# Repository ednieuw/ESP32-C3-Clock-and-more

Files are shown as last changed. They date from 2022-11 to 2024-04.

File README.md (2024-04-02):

<h1 class="auto-style10">ESP32-C3-12F ESP32-S3 Word clock, HTML page, NTP, BLE to phone and more</h1>

Ed's GitHub stats (https://github.com/anuraghazra/github-readme-stats)

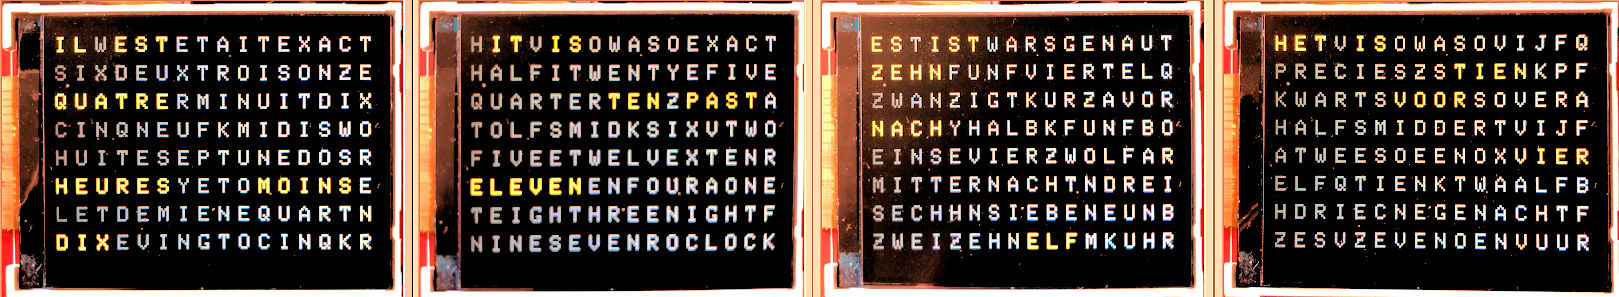
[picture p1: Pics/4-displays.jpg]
4-displays

<p><span class="auto-style10">A small clock that displays the time in words in Dutch, English, French and 
German.<br />The clock is able to receive time via NTP from the internet. <br />
Settings can be controlled via a webpage, PC and Bluetooth LE.</span><br />
Also info here: <a href="https://ednieuw.home.xs4all.nl/Woordklok/ESP32C3AndMore/ESP32C3ClockAndMoreV.html">  
On my home page for the latest info</a>.	
<p><span class="auto-style10">The clock is built with an ESP32-C3-12F kit.</span><br class="auto-style10" />
<span class="auto-style10">The software is written with the Arduino IDE 1.8.19.</span><br class="auto-style10" />
<br class="auto-style10" />
<span class="auto-style10">The software contains coding to use:</span><br class="auto-style10" />
1 ILI9314 colour display</br>
2 BLE nRF UART connection with a phone with an option to send strings longer than 20 bytes</br>
3 Time zone corrected time with daylight savings from a NTP server via WIFI</br>
4 RGBCW LED control on the MCU board</br>
5 RTC for time keeping when off line</br>
6 LDR analogue readings&nbsp;and control of display intensity</br>
7 Storage of the settings in the ESP32-C3 SPIFSS Flash memor</br>
8 Menu driven control of preferences with serial monitor, BLE and WIFI-html page</br>
9&nbsp;Four languages to display time</br>
10 SK6812 RGBW /WS2812 RGB LED strip support to make a word clock</br>
11 Analog clock.</br>
12 OTA. Upgrade the software over the air without USB-cable</br> </span></p>
<p style="width: 840px"><br class="auto-style10" />
<table class="auto-style12">
<tr>
<td style="width: 377px" valign="bottom"><span class="auto-style3"><br />
</span><span class="auto-style11">Het was tien over tien&nbsp;&nbsp;&nbsp;&nbsp; 10:13:00</span><br class="auto-style11" />
<span class="auto-style11">Il est dix heures et quart 10:14:00</span><br class="auto-style11" />
<span class="auto-style11">Il est dix heures et quart 10:15:00</span><br class="auto-style11" />
<span class="auto-style11">Het is kwart over tien&nbsp;&nbsp;&nbsp;&nbsp; 10:16:00</span><br class="auto-style11" />
<span class="auto-style11">Es war viertel nach zehn&nbsp;&nbsp; 10:17:00</span><br class="auto-style11" />
<span class="auto-style11">It was quarter past ten&nbsp;&nbsp;&nbsp; 10:18:00</span><br class="auto-style11" />
<span class="auto-style11">Il est dix heures vingt&nbsp;&nbsp;&nbsp; 10:19:00</span><br class="auto-style11" />
<span class="auto-style11">Es ist zehn vor halb elf&nbsp;&nbsp; 10:20:00</span><br class="auto-style11" />
<span class="auto-style11">Het is tien voor half elf&nbsp; 10:21:00</span><br class="auto-style11" />
<span class="auto-style11">It was twenty past ten&nbsp;&nbsp;&nbsp;&nbsp; 10:22:00</span><br class="auto-style11" />
<span class="auto-style11">It was twenty past ten&nbsp;&nbsp;&nbsp;&nbsp; 10:23:00</span><br class="auto-style11" />
<span class="auto-style11">Het is vijf voor half elf&nbsp; 10:24:00</span><br class="auto-style11" />
<span class="auto-style11">Es ist funf vor halb elf&nbsp;&nbsp; 10:25:00</span><br class="auto-style11" />
<span class="auto-style11">It is twenty five past ten 10:26:00</span><br class="auto-style11" />
<span class="auto-style11">Es war funf vor halb elf&nbsp;&nbsp; 10:27:00</span><span class="auto-style3"><br />
<br />
</span></td>
<td>
<span class="auto-style3">
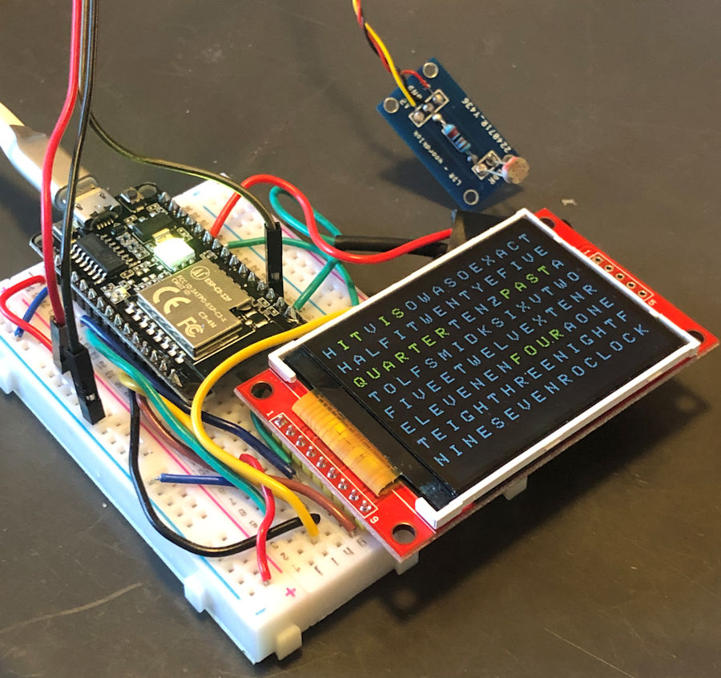
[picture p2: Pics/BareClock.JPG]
Bare clock
</span></td>
</tr>
<tr>
<td class="auto-style10" colspan="2">Display of the time in the serial output</td>
</tr>
</table>
<br class="auto-style10" />
</p>
<h2 style="width: 840px"><strong>Introduction</strong></h2>
<p style="width: 840px" class="auto-style10">The ESP32-C3-12F is a cheap, versatile Micro Computer Unit (MCU). <br />
Competitors at this moment, end 2022, I have played with are the Arduino MKR1010 
and IOT33, the Arduino RP2040 Connect and Raspberry Pico W.<br />
The RP2040 Connect is my favorite at the moment while it pins are compatible with the Arduino 
Nano / Every and my designed printed circuit boards (PCB) can still be used, it has a lot a memory and more than enough speed 
for my projects<br />
A <a href="https://ednieuw.home.xs4all.nl/Woordklok/Pocuter/PocuterWordClockV.html">kickstarter project</a> using the 
ESP32-C3 with an OLED display forced me to study this architecture. <br />
A piece of cake was my first thought and I started to convert the word clock 
into the ESP-C3.<br />
Source code for an Arduino also compiles and uploads with the Arduino IDE 
in a ESP32-C3.<br />
But many libraries are different and changing from 5V and 3.3V was needed.&nbsp;
<br />
The result is the program and design below.&nbsp; <br />
Everything works and the time is displayed in words in the display.<br />
The program's origin was a <a href="https://ednieuw.home.xs4all.nl/Woordklok/Bouwpakket/WoordklokWitteLEDs.html">word 
clock running with an ATMEGA328 </a>processor. The software was then converted 
to be used with <a href="https://ednieuw.home.xs4all.nl/Woordklok/Bouwpakket/WoordklokSK6812.htm">SK6812 RGBW</a> or<a href="https://ednieuw.home.xs4all.nl/Woordklok/Bouwpakket/Woordklok-Kleur.htm">WS2812 
RGB</a> LED-strips. Time was received with a DCF77 receiver.<br />
<br />
This ESP32-C3 program is able to connect to a NTP service on the internet and is 
attached to an ILI9314 display to print the time as text. The ILI9341 colour display is, around €10, very cheap 
but not very fast. For this clock it is not an issue. When no connection is made 
the clock runs on the internal RTC but will drift.<br />
Settings can be changed via Bluetooth on a phone or with a webpage in a browser. <br />
No cloud service is used or needed to operate this clock.&nbsp;</p>
<h2 style="width: 840px"><strong>Hardware</strong></h2>
<p style="width: 840px" class="auto-style10"><strong>Materials<br />
- </strong>ESP32-C3-12F<br />
- ILI9341 display<br />
- LDR (Light Dependent Resistor) type GL5516 or GL5528<br />
- Resistors 1 kOhm, 10 kOhm and optional 22 kOhm<br />
- 2N2222 or 2N3906 PNP transistor <strong><br />
<br />
</strong>
<span class="auto-style10">- For IOS:&nbsp;
<a href="https://apps.apple.com/nl/app/ble-serial-pro/id1632245655?l=en">BLE 
Serial Pro</a>. (Turn on Fast BLE with option Z in the menu)</span><br />
<span class="auto-style10">- For Android :
<a href="https://play.google.com/store/apps/details?id=de.kai_morich.serial_bluetooth_terminal">
Serial Bluetooth terminal</a>. (Turn off (default) Fast BLE)</span></p>
<p style="width: 840px" class="auto-style10">The program 
'ESP32C3-WordClockV009.ino' or newer can be uploaded in the 
ESP32-C3-12F with the Arduino IDE 1.8.19 or newer. The Arduino IDE 2.0.2 
(November 2022) was not able to compile this program due to a bug in the IDE.<br /> 
The libraries needed to compile can be installed with the Arduino IDE (Tools -> Manage libraries) or be copied from the V009LibsAndBuilt.zip in the folder 'libraries' located in the sketch book location folder of the IDE. <br />
<br />
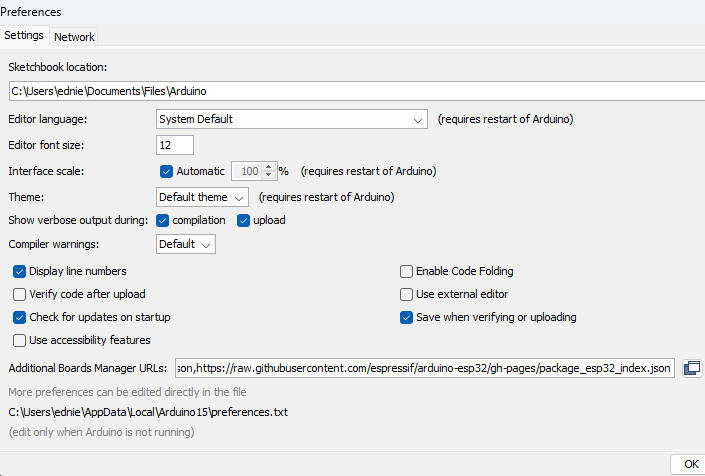
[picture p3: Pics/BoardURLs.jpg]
Boardmanager
</p>
<p style="width: 840px" class="auto-style10"><br />
Add the string in Additional Boards Manager URLs in File-&gt; Preference of the IDE<strong><br />
</strong><span class="auto-style11"><span class="auto-style13">
https://raw.githubusercontent.com/espressif/arduino-esp32/gh-pages/package_esp32_index.json
</span><br />
<br />
</span>Restart the IDE and install the ESP32 boards.<br />
<br />
Choose the 'ESP32C3 Dev Module' as board and set the partition scheme to 'huge'
<br />
in the IDE menu --&gt; Tools.</p>
<p style="width: 840px" class="auto-style10"><strong> <br />
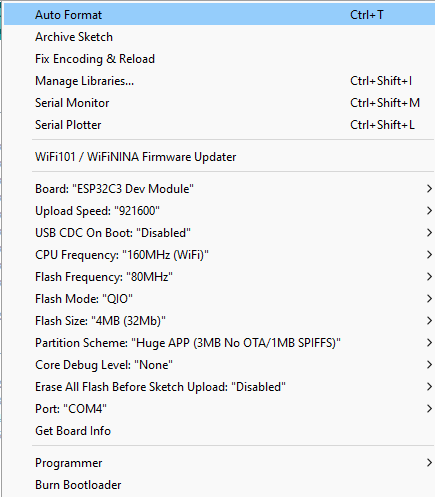
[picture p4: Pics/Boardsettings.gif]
IDE settings
<br />
<br />
</strong>If the program compiles without errors and uploads into the ESP-C3 the 
hardware can be connected to the board.<br />
&nbsp;<strong><br />
</strong>Connect the DC/RS, RST, MOSI, SCK to respectively GPIO pins 06, 07, 08 and 09.<br />
MISO is not used because no data comes back from the display. <br />
CS is connected to GND. <br />
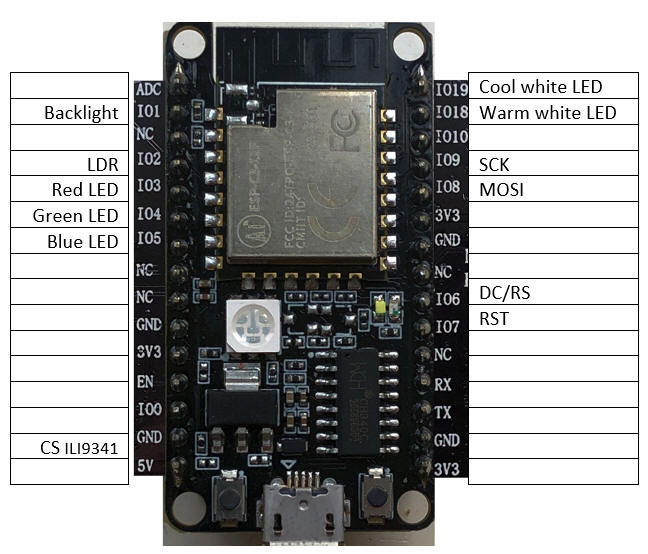
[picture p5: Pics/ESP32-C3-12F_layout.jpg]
ESP32-C3-12F connections
<br />
<br />
To control the brightness of a connected LED-strip or the back light of the 
display a LDR measures the 
luminosity and dims the LEDs or back light accordingly by PWM on the pin that 
powers the back light or changes the RGBW LED intensity in the software. <br />
<br />
If no LDR is attached 
set the minimum light intensity to 254 in the menu and the maximum to 255.<br />
<br />
The back light of the ILI9341 uses 50 - 100 mA and the pins of the ESP32-C3-12F 
supply 12mA (or 40mA?). Therefore a 2N2222 PNP transistor is used. A BC327 did 
not work. Probably 3V3 is too less to switch the transistor. A 2N3906 may also 
work.<br />
<br />
Connect the 1 kOhm resistor to pin GPIO 01 that controls the intensity of the 
backlight.<br />
<br />
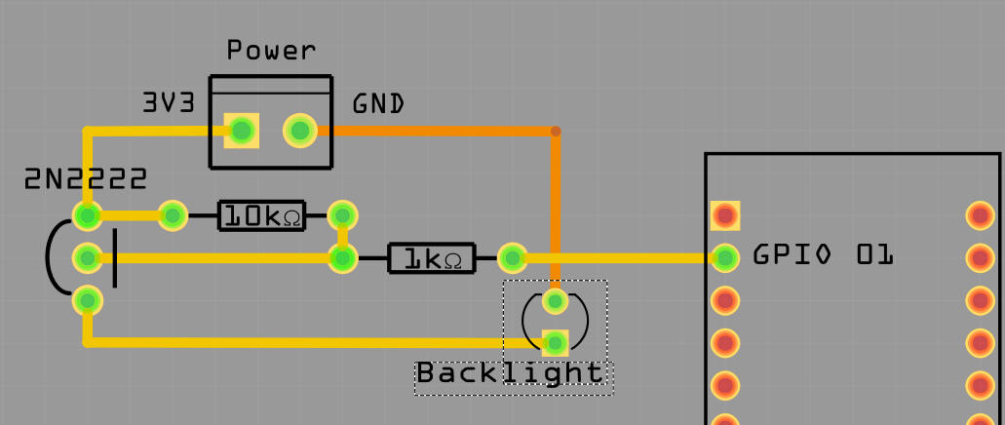
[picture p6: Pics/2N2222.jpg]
PWM 2N2222
<br />
</p>
<p style="width: 840px" class="auto-style10">The LDR is connected via a 10 - 22 
kOhm LDR to ground. The pin A2 is connected to GPIO 02.</p>
<p style="width: 840px" class="auto-style10">With option K in the menu display 
of the LDR readings are printed every second. With the options minimum, maximum 
and slope in the menu the light intensity of the display can be controlled<br />
<br />
<a href="https://ednieuw.home.xs4all.nl/Woordklok/LDR/GL55xxLDRs.html">More about the LDR and it types</a><br />
</p>
<p style="width: 840px" class="auto-style10">
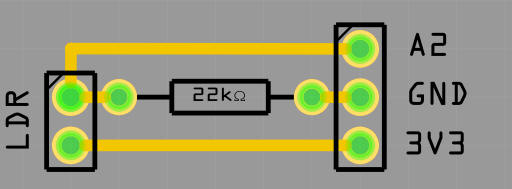
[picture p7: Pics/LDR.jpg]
LDR schakeling
</p>
<p style="width: 840px" class="auto-style10">Connecting the LDR to GPIO 00 
failed. The pin did not go low to 0V. It is used for WIFI?<br />
Almost all&nbsp; the pins are used now. <br />
GPIO 03, 04, 05, 18 and 19 are used for the LEDs on 
the MCU. GPIO 20 and 21 are probably used for the serial USB connection.
&nbsp; <br />

 

</p>
<h2 style="width: 840px"><strong><span class="auto-style10">First Use</span></strong></h2>
<p style="width: 840px"><span class="auto-style10">When the MCU is started and running properly the LED on the 
board will pulse red every second. 
</span> 
<br class="auto-style10" />
<span class="auto-style10">When connected to WIFI&nbsp; the same led will also pulse green.&nbsp; 
</span> <br class="auto-style10" />
<span class="auto-style10">Press the
the top right button to see the IP-address, time and date of the clock.
</span>
<br class="auto-style10" />
<span class="auto-style10">Date and IP-address will disappear as a new minute starts.</span><br class="auto-style10" />
<span class="auto-style10">Enter the IP-address in a browser or connect 
via Bluetooth and send the character 'I' to see for the menu.</span><br class="auto-style10" />
<span class="auto-style10">In the menu the name of the router to connect to, the SSID, and its password can 
be entered. </span> <br class="auto-style10" />
<br class="auto-style10" />
IP-address<br class="auto-style10" />
</p>
<h2><span class="auto-style10"><strong>Control of the clock</strong>&nbsp;
</span></h2>
<p><span class="auto-style10">If the clock is connected to the internet it will seek contact with a time 
server. (NTP connection can be turned off in the menu). </span> <br class="auto-style10" />
<span class="auto-style10">The time zone is set to UTC+1 Amsterdam but can be changed in the menu.</span><br class="auto-style10" />
<span class="auto-style10">To connect to a WIFI network a SSID and password must be entered.</span><br class="auto-style10" />
<span class="auto-style10"><br />
There are a few methods:</span><br class="auto-style10" />
<span class="auto-style10">1. Connect the MCU with a serial cable to a PC and use a serial terminal. I 
use the Arduino IDE or <a href="https://www.compuphase.com/software_termite.htm">
Termite</a> as serial terminal.</span><br class="auto-style10" />
<br class="auto-style10" />
<span class="auto-style10">Sending the character 'I' for information will display the menu followed with the actual 
settings of several preferences.</span></p>
<p>
<table style="width: 51%" class="auto-style12">
<tr>
<td style="width: 342px">
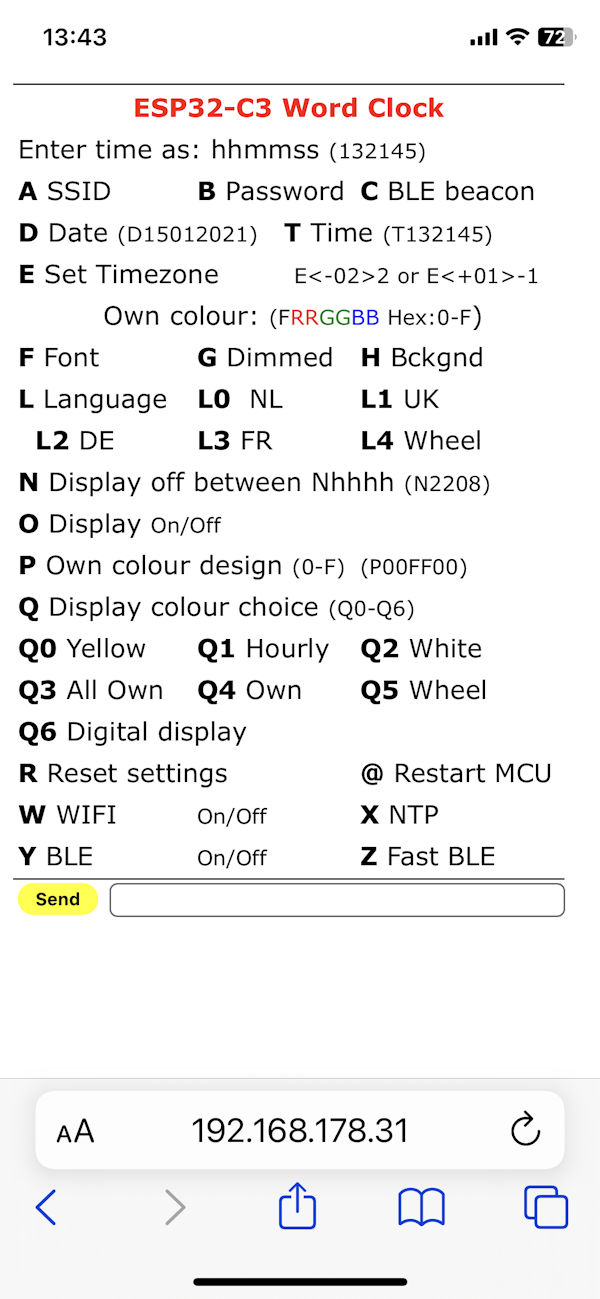
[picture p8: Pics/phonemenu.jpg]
Menu on iPhone
</td>
<td style="width: 415px">
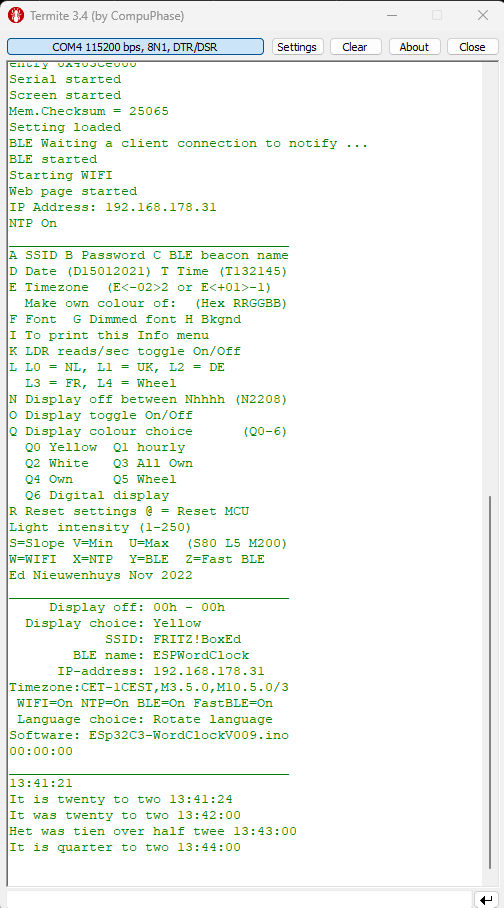
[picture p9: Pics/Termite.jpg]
Termite terminal
</td>
</tr>
<tr>
<td style="width: 342px" class="auto-style10">HTML page on iPhone.</td>
<td style="width: 415px"><br class="auto-style10" />
<span class="auto-style10">Termite Terminal on a PC</span></td>
</tr>
</table>
<br class="auto-style10" />
</p>
<table style="width: 919px">
<tr>
<td style="width: 550px">
<p><span class="auto-style10">2. USE the BLE nRF connection with an UART serial terminal app 
to control it with your mobile phone or tablet.</span><br class="auto-style10" />
<span class="auto-style10"><br />
Use the IOS app for iPhone or iPad:&nbsp;
<a href="https://apps.apple.com/nl/app/ble-serial-pro/id1632245655?l=en">BLE 
Serial Pro</a>. <br />
Turn on Fast BLE with option Z in the menu.</span><br class="auto-style10" />
<br class="auto-style10" />
<span class="auto-style10">For Android use:
<a href="https://play.google.com/store/apps/details?id=de.kai_morich.serial_bluetooth_terminal">
Serial Bluetooth terminal</a>. <br />
Turn off (default) Fast BLE in the menu.</span>
</p>
<p>
<span class="auto-style10">Start the 
app and find the MCU in the list of devices and connect to it. You 
can change it's beacon name in the menu with option C.</span><br class="auto-style10" />
<br class="auto-style10" />
<span class="auto-style10">In both cases 
<strong>send the character I 
of Information and the menu shows up</strong></span>.<br class="auto-style10" />
<span class="auto-style10">Enter the first character of the setting you want to change followed with a code.</span><br class="auto-style10" />
<span class="auto-style10">Some entries just toggle On and Off. Like the W to set WIFI Off or On. 
</span> 
</p>
<p style="width: 600px"><span class="auto-style10">To change the SSID and password:</span><br class="auto-style10" />
<span class="auto-style10"><strong>A</strong></span><span class="auto-style7"><strong>my-ssid</strong></span><span class="auto-style10"> 
and send this command. Eg AFRITZ!Box01 or aFRITZ!Box01. Starting with an upper 
or lower case character is an identical instruction in the command string</span><br class="auto-style10" />
<span class="auto-style10">Then&nbsp; <strong>B</strong></span><span class="auto-style1"><span class="auto-style10"><strong>my-password</strong> and send that password.</span><br class="auto-style10" />
<span class="auto-style10">
<strong>Cbroadcastname</strong>&nbsp;will change to name displayed in the Bluetooth 
connection list.&nbsp; </span> <br class="auto-style10" />
<span class="auto-style10">If the length of the SSID and/or password is less then 5 characters the WIFI 
will be turned off automatically. This will speed up startup time if no internet connection is available</span><br class="auto-style10" />
<span class="auto-style10">Use a length of minimal 8 characters for SSID and password.</span><br class="auto-style10" />
<span class="auto-style10">Check in the menu (third row from the bottom) if WIFI and NTP are on.</span><br class="auto-style10" />
<span class="auto-style10">If WIFI is connected the LED on the MCU will pulse green.</span><br class="auto-style10" />
</span><br class="auto-style10" /><span class="auto-style10">Enter @ to reset the 
MCU. It will restart and connections will be made.</span><br class="auto-style10" />
<br class="auto-style10" />
<span class="auto-style10">To set a time zone. Send the time zone string between the quotes prefixed with 
the character E or e.</span><br class="auto-style10" />
<span class="auto-style10">See the time zones at the bottom of this page.</span><br class="auto-style10" />
<span class="auto-style10">For example; if you live in Australia/Sydney send the string: eAEST-10AEDT,M10.1.0,M4.1.0/3</span></p>
</td>
<td valign="bottom">
<p class="auto-style10">&nbsp;</p>
<pre>___________________________________
A SSID B Password C BLE beacon name
D Date (D15012021) T Time (T132145)
E Timezone (E&lt;-02&gt;2 or E&lt;+01&gt;-1)
Make own colour of: (Hex RRGGBB)
F Font G Dimmed font H Bkgnd
I To print this Info menu
K LDR reads/sec toggle On/Off
L L0 = NL, L1 = UK, L2 = DE
L3 = FR, L4 = Wheel
N Display off between Nhhhh (N2208)
O Display toggle On/Off
Q Display colour choice (Q0-6)
Q0 Yellow Q1 hourly
Q2 White Q3 All Own
Q4 Own Q5 Wheel
Q6 Digital display
R Reset settings @ = Reset MCU
Light intensity (1-250)
S=Slope V=Min U=Max (S80 L5 M200)
W=WIFI X=NTP Y=BLE Z=Fast BLE
Ed Nieuwenhuys Nov 2022
___________________________________
Display off: 00h - 00h
Display choice: Yellow
SSID: FRITZ!BoxEd
BLE name: ESPWordClock
IP-address: 192.168.178.31
Timezone:CET-1CEST,M3.5.0,M10.5.0/3
WIFI=On NTP=On BLE=On FastBLE=On
Language choice: Rotate language
Software: ESp32C3-WordClockV009.ino
09:27:22
___________________________________</pre>
</td>
</tr>
<tr>
<td style="width: 550px" class="auto-style10">&nbsp;</td>
<td class="auto-style10">Menu shown in serial output.</td>
</tr>
</table>
<p><span class="auto-style10">If no WIFI is not used check at the bottom of the menu if WIFI is OFF. </span> 
<br class="auto-style10" />
<span class="auto-style10">The clock will start much quicker because it 
will not try to connect.</span><br class="auto-style10" />
Pocuter menu bottom</p>
<p><span class="auto-style10">As mentioned before the clock can be controlled with the WIFI webpage or BLE 
UART terminal app.</span><br class="auto-style10" />
<span class="auto-style10">When the clock is connected to WIFI the IP-address is displayed in the Digital display.</span><br class="auto-style10" />
<span class="auto-style10">Enter this IP-address numbers and dots (for example: 192.168.178.31) in the browser of your mobile or PC where you type 
your internet addresses (URL).</span><br class="auto-style10" />
<span class="auto-style10">Or</span><br class="auto-style10" />
<span class="auto-style10">Open the BLE terminal app. Look for the WordClock to connect to and connect.</span><br class="auto-style10" />
<span class="auto-style10">BLE connection can be made with my app
<a href="https://ednieuw.home.xs4all.nl/BLESerial/BLESerialPRO.html">BLE Serial 
pro</a> on the
<a href="https://apps.apple.com/nl/app/ble-serial-pro/id1632245655?l=en">app 
store</a> for Apple IOS devices. </span> <br class="auto-style10" />
<span class="auto-style10">For Android
<a href="https://play.google.com/store/apps/details?id=com.nordicsemi.nrfUARTv2&amp;hl=en&amp;gl=US"> 
&nbsp;nRF UART terminal program </a>and
<a href="https://play.google.com/store/apps/details?id=de.kai_morich.serial_bluetooth_terminal">
Serial Bluetooth terminal</a>. <br />
Unfortunately these Android apps 
can not read strings longer than 20 characters.</span><br class="auto-style10" />
<span class="auto-style10">If you see a garbled menu enter and send the character 'Z' to select the slower 
transmission mode.</span><br class="auto-style10" />
<br class="auto-style10" />
<span class="auto-style10">
<strong>Settings are set by entering the first character of a command following by 
parameters if necessary.</strong></span>
<span class="auto-style10"><br />
For example to set the colours of the characters in the display 
to white enter: Q2</span><br class="auto-style10" />
<br class="auto-style10" />
<span class="auto-style10">To shown random all four languages every minute send L4.</span><br class="auto-style10" />
<br class="auto-style10" />
<span class="auto-style10">Set the time by entering T130245. (130245 will also work)</span><br class="auto-style10" />
<br class="auto-style10" />
<span class="auto-style10">Turn off WIFI by sending a W.</span></p>
<p class="auto-style10">Reset the MCU with the character @.</p>
<p><span class="auto-style10">Reset to default setting by send R.<br />
</span><br class="auto-style10" />
<span class="auto-style10">In the BLE connection the SSID and password will be shown. 
</span> <br class="auto-style10" />
<table cellspacing="6" class="auto-style2" style="width: auto">
<tr>
<td style="width: 318px">
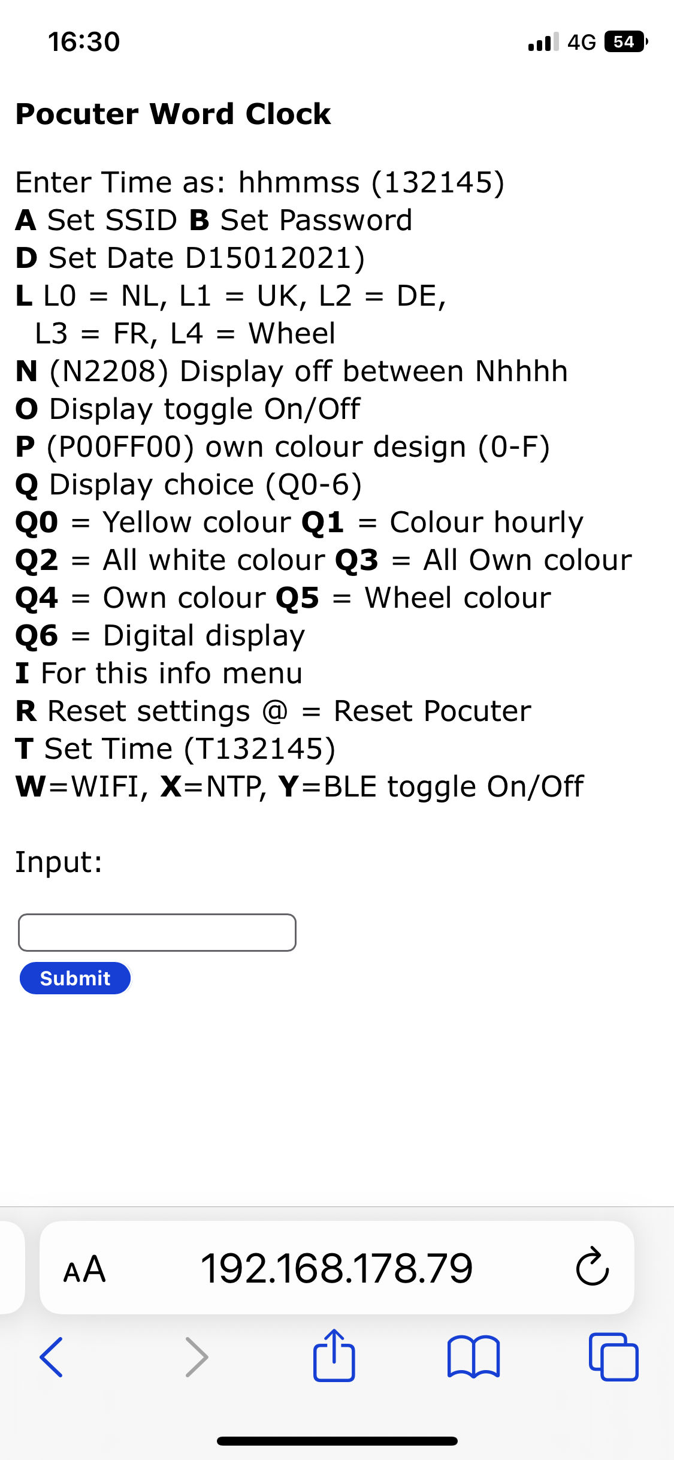
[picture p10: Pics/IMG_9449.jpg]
Phone
</td>
<td>
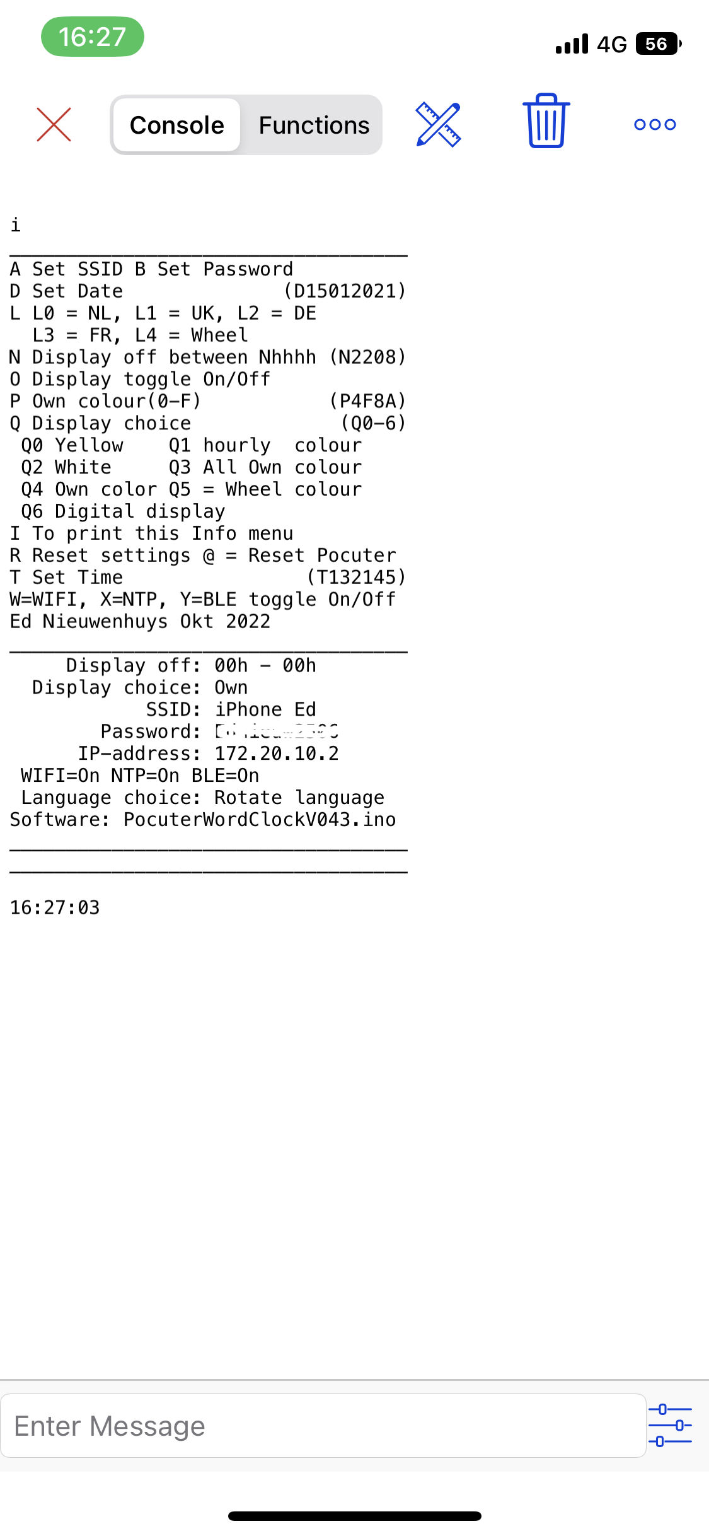
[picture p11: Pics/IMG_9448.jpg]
WIFI-BLE
</td>
</tr>
<tr>
<td style="width: 318px" class="auto-style10">HTML page</td>
<td class="auto-style10">BLE menu</td>
</tr>
</table>
</p>
<h2><span class="auto-style10"><strong>Detailed description</strong></span></h2>
<pre>___________________________________
A SSID B Password C BLE beacon name
D Date (D15012021) T Time (T132145)
E Timezone (E&lt;-02&gt;2 or E&lt;+01&gt;-1)
Make own colour of: (Hex RRGGBB)
F Font G Dimmed font H Bkgnd
I To print this Info menu
K LDR reads/sec toggle On/Off
L L0 = NL, L1 = UK, L2 = DE
L3 = FR, L4 = Wheel
N Display off between Nhhhh (N2208)
O Display toggle On/Off
Q Display colour choice (Q0-6)
Q0 Yellow Q1 hourly
Q2 White Q3 All Own
Q4 Own Q5 Wheel
Q6 Digital display
R Reset settings @ = Reset MCU
Light intensity (1-250)
S=Slope V=Min U=Max (S80 L5 M200)
W=WIFI X=NTP Y=BLE Z=Fast BLE
Ed Nieuwenhuys Nov 2022
___________________________________
Display off: 00h - 00h
Display choice: Yellow
SSID: FRITZ!BoxEd
BLE name: ESPWordClock
IP-address: 192.168.178.31
Timezone:CET-1CEST,M3.5.0,M10.5.0/3
WIFI=On NTP=On BLE=On FastBLE=On
Language choice: Rotate language
Software: ESp32C3-WordClockV009.ino
09:27:22
___________________________________</pre>
<p>
<span class="auto-style10">With the menu many preferences can be set. <br />
These preferences are permanently stored in the ESP32-C3 SPIFFS-storage space.</span><br class="auto-style10" />
&nbsp;<br class="auto-style10" />
<span class="auto-style10">Enter the first character in the menu of the item to be changed followed with the parameter.</span><br class="auto-style10" />
<span class="auto-style10">For most entries upper and lower case are identical.</span><br class="auto-style10" />
<br class="auto-style10" />
<span class="auto-style10">
<strong>A SSID B Password C BLE beacon name</strong></span><br class="auto-style10" />
<span class="auto-style10">Change the name of the SSID of the router to be connected to. 
</span> <br class="auto-style10" />
<span class="auto-style10">aFRITZ!BoxEd or AFRITZ!BoxEd</span><br class="auto-style10" />
<span class="auto-style10">Then enter the password. For example: BSecret_pass</span><br class="auto-style10" />
<span class="auto-style10">Restart the MCU by sending @.</span><br class="auto-style10" />
<span class="auto-style10">Entering a single 'b' will show the used password. This Easter egg can can used 
to check if a valid password was entered</span><br class="auto-style10" />
<br class="auto-style10" />
<span class="auto-style10">
<strong>D Set Date</strong>&nbsp; and <strong>T Set Time</strong></span> 
<br class="auto-style10" />
<span class="auto-style10">If you are not connected to WIFI you have to set the time and date by hand.</span><br class="auto-style10" />
<span class="auto-style10">For example enter: D06112022 to set the date to 6 November 2022.</span></p>
<p class="auto-style10">Enter for example T132145 (or 132145 , or t132145)&nbsp; to set the time to 45 seconds and 21 minutes past 
one o'clock.</p>
<p><span class="auto-style10"><strong>E Set Timezone E&lt;-02&gt;2 or E&lt;+01&gt;-1</strong></span><br class="auto-style10" />
<span class="auto-style10">At the bottom of this page you can find the time zones used in 2022. 
</span> <br class="auto-style10" />
<span class="auto-style10">It is a rather complicated string and it is therefore wise to copy it.</span><br class="auto-style10" />
<span class="auto-style10">Let's pick one if you happen to live here: Antarctica/Troll,"&lt;+00&gt;0&lt;+02&gt;-2,M3.5.0/1,M10.5.0/3"</span><br class="auto-style10" />
<span class="auto-style10">Copy the string between the " " 's and send it starting with an 'E' or 'e' in front.</span><br class="auto-style10" />
<span class="auto-style10">E&lt;+00&gt;0&lt;+02&gt;-2,M3.5.0/1,M10.5.0/3</span></p>
<p><em><span class="auto-style10">Time zones and daylight savings should be ended and replaced by one universal 
date and time for the whole planet cq universe. But that is my opinion.</span></em></p>
<p><strong><span class="auto-style10">Make own colour of: (Hex RRGGBB)</span><br class="auto-style10" />
<span class="auto-style10">F Font G Dimmed font H Bkgnd</span></strong><br class="auto-style10" />
<span class="auto-style10">You can set the colours of the highlighted and dimmed characters and&nbsp;the background.</span><br class="auto-style10" />
<span class="auto-style10">The time is shown with the colour defined when Display choice Q3 or Q4 
is chosen and the rest of the not highlighted characters are coloured with the settings 
from Dimmed 
font.</span><br class="auto-style10" />
<span class="auto-style10">The format to be entered is hexadecimal. 0123456789ABCDEF are the character that 
can be used.</span><br class="auto-style10" />
<span class="auto-style10">The command is 2 digits for Red followed with&nbsp;two 
digits for Green and ending 
with two digits for Blue. </span> <br class="auto-style10" />
<span class="auto-style10">To colour the characters intense red enter FF0000 prefixed with the 
character F, G 
or H.</span><br class="auto-style10" />
<span class="auto-style10">To set the background to intense blue enter: H0000FF</span><br class="auto-style10" />
<span class="auto-style10">To set the dimmed character to dark gray enter for example: G191919. 
<br />
You get 
gray if red, green and blue has the same intensity.</span></p>
<p><span class="auto-style10"><strong>I To print this Info menu</strong></span><br class="auto-style10" />
<span class="auto-style10">Print the menu to Bluetooth and the serial monitor 
when connected with an USB-cable.</span><br class="auto-style10" />
</p>
<p class="auto-style10"><strong>K LDR reads/sec toggle On/Off<br />
</strong>Prints the LDR-readings and the calculated intensity output.</p>
<p>
<span class="auto-style10">
<strong>L L0 = NL, L1 = UK, L2 = DE, L3 = FR, L4 = Wheel</strong></span><br class="auto-style10" />
<span class="auto-style10">You can choose between four languages to display or show them randomly every 
minute.</span><br class="auto-style10" />
<br class="auto-style10" />
<span class="auto-style10">
<strong>N Display off between Nhhhh (N2208)</strong></span><br class="auto-style10" />
<span class="auto-style10">With N2208 the display will be turned off between 22:00 and 
08:00.</span><br class="auto-style10" />
<br class="auto-style10" />
<span class="auto-style10">
<strong>O Display toggle On/Off</strong></span><br class="auto-style10" />
<span class="auto-style10">O toggles the display off and on.</span></p>
<p><strong><span class="auto-style10">Q Display colour choice (Q0-6)</span><br class="auto-style10" />
<span class="auto-style10">Q0 Yellow Q1 hourly
Q2 White Q3 All Own
Q4 Own Q5 Wheel
Q6 Digital display</span></strong><br class="auto-style10" />
<br class="auto-style10" />
<span class="auto-style10">Q0 will show the time with yellow words.</span><br class="auto-style10" />
<span class="auto-style10">Q1 will show every hour another colour.</span><br class="auto-style10" />
<span class="auto-style10">Q2 shows all the texts white.</span><br class="auto-style10" />
<span class="auto-style10">Q3 and Q4 uses you own defined colours.</span><br class="auto-style10" />
<span class="auto-style10">Q5 will follow rainbow colours every minute.</span><br class="auto-style10" />
<span class="auto-style10">Q6 is the digital display with the IP-address and date until seconds are 00.</span><br class="auto-style10" />
<span class="auto-style10">The selected choice is displayed at the bottom of the menu.</span><br class="auto-style10" />
<span class="auto-style10">Send an 'I' to display the latest's settings</span></p>
<p><span class="auto-style10"><strong>R Reset settings </strong></span>
<br class="auto-style10" />
<span class="auto-style10">R will set all preferences to default settings and clears the SSID and password.</span></p>
<p><span class="auto-style10"><strong>Light intensity (1-250)</strong></span><strong><br class="auto-style10" />
</strong><span class="auto-style10"><strong>S=Slope V=Min&nbsp; U=Max&nbsp; 
(S100 L5 M200)</strong></span></p>
<p>
<table style="width: 100%">
<tr>
<td><span class="auto-style10">To control the light intensity three parameters 
can be set.</span><br class="auto-style10" />
<span class="auto-style10">The values ranges between 0 and 255.</span><br class="auto-style10" />
<span class="auto-style10">The minimal light intensity is to avoid that the 
display turns completely off when it is dark. <br />
It also prevents flickering when 
the input value are very low, like 2 and 3 bits. </span><br class="auto-style10" />
<span class="auto-style10">Values ranging between 5 and 20 are suggested. When 
no LDR is attached the Min value can be set to 255.<br />
The maximum light intensity is 255 bits for 100% intensity. </span>
<br class="auto-style10" />
<span class="auto-style10">The Slope (sensitivity) controls the speed at with the maximum 
value is reached. <br />
It multiplies the reading as a percentage. So, entering
100 is a multiplication by one. <br />
The placement and sensitivity of your LDR can be 
adjusted with this parameter Slope.</span></td>
<td><span class="auto-style10">
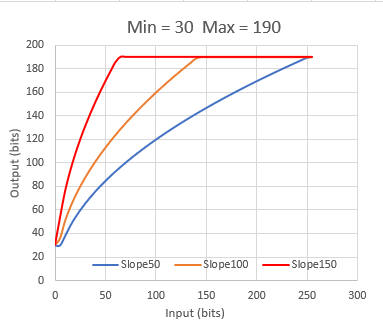
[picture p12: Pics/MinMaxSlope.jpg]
Min Max Slope
<br />
The effect of the value of the slope on the light intensity of the LEDs 
or display.</span></td>
</tr>
</table>
</p>
<table style="width: 100%">
	<tr>
		<td><span class="auto-style10">
		<strong>@ = Restart MCU<br class="auto-style10" />
		</strong>@ will restart the MCU. This is handy when the SSID, password, et cetera are 
changed and the program must be restarted.<strong><br />
		<br />
		W=WIFI, X=NTP, Y=BLE<br />
		</strong>Toggle WIFI, NTP and BLE on and off.<br />
		Sending the character will toggle it on or off. <br />
		At the bottom of the menu the 
state is printed.<br />
		</span></td>
		<td>
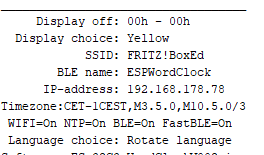
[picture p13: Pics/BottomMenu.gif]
Bottom menu
</td>
	</tr>
	<tr>
		<td colspan="2">
<p><span class="auto-style10"><strong>Z Fast BLE</strong></span><br class="auto-style10" />
<span class="auto-style10">The
BLE UART protocol sends default packets of 20 bytes. Between every packet there is a delay of 50 
msec</span><br class="auto-style10" />
<span class="auto-style10">The IOS BLEserial app, and maybe others too, is able to receive packets of 80 
bytes or more before characters are missed. <br />
With most apps you will see these will truncate the long strings of the menu.
<br />
Then turn off Fast BLE. </span> 
<br class="auto-style10" />
<span class="auto-style10">Option Z toggles between the long and short packages.&nbsp; 
</span> </p>
<p class="auto-style10">
Settings are stored in the SPIFFS space from the ESP32-C3</p>
		</td>
	</tr>
</table>
<h2>
<strong>Compilation and uploading</strong></h2>
<p class="auto-style10">The settings of the ESP32C3 board is as follows.<br />
Partition scheme is huge.<br />
Remember to install the ESP32 boards as explained above in the chapter Materials<br />
</p>
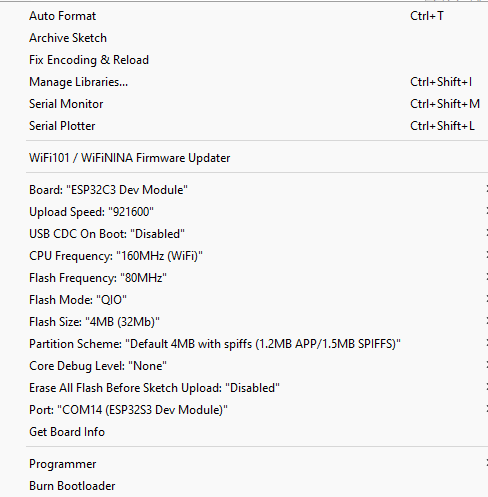
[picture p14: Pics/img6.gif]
Board settings

<p class="auto-style10">&nbsp;</p>
<p class="auto-style10"><strong>Program explanation</strong></p>
<p><span class="auto-style10">The program uses the following standard libraries. </span> 
<br class="auto-style10" />
</p>
<pre><span class="auto-style11">// ESP32-C3 Includes defines and initialisations</span>

<span class="auto-style11">#include &lt;NimBLEDevice.h&gt;          // For BLE communication https://github.com/h2zero/NimBLE-Arduino</span>
<span class="auto-style11">#include &lt;ESPNtpClient.h&gt;          // https://github.com/gmag11/ESPNtpClient</span>
<span class="auto-style11">#include &lt;WiFi.h&gt;                  // Used for NTP time and web page</span>
<span class="auto-style11">#include &lt;AsyncTCP.h&gt;              // Used for webpage https://github.com/me-no-dev/ESPAsyncWebServer</span>
<span class="auto-style11">#include &lt;ESPAsyncWebServer.h&gt;     // Used for webpage https://github.com/me-no-dev/ESPAsyncWebServer</span>
<span class="auto-style11">#include &lt;Preferences.h&gt;           // for storage in SPIFFS</span>
<span class="auto-style11">#include "Colors.h"                // Definition of the colour list</span></pre>
<p><span class="auto-style10">Colors.h is included in the program as a TAB in 
the IDE. It contains color names and it associated RGB values</span><br class="auto-style10" />
<span class="auto-style10">The other TAB is the web page to display in the 
browser.<br />
The&nbsp;#include "Webpage.h" to load the webpage is a few lines further in the code </span> 
<br class="auto-style10" />
<span class="auto-style10"><br />
I made the web page in the free 'Microsoft Expression Web 4'. It is not 
maintained anymore but has more than enough functionalities for our purposes.<br />
<br />
To copy the code from the MS-Expression:</span><br class="auto-style10" />
<span class="auto-style10">In the bottom line of the window of MS-Expression click&nbsp;'Split'.<br />
In the upper half the raw HTML Code is displayed and in the bottom half the 
Design window.<br />
Copy in the Code window all the HTML 
code <br />
Go to the Arduino IDE and paste it in the webpage.h TAB between:</span><span class="auto-style11"><br />
R"rawliteral( </span><span class="auto-style10">&nbsp;... and ...&nbsp;
</span><span class="auto-style11">)rawliteral";<br />
<br />
</span><span class="auto-style10">Or copy the the code from the webpage.h into 
MSexpression Code area and redesign the page as you like</span></p>
<p>
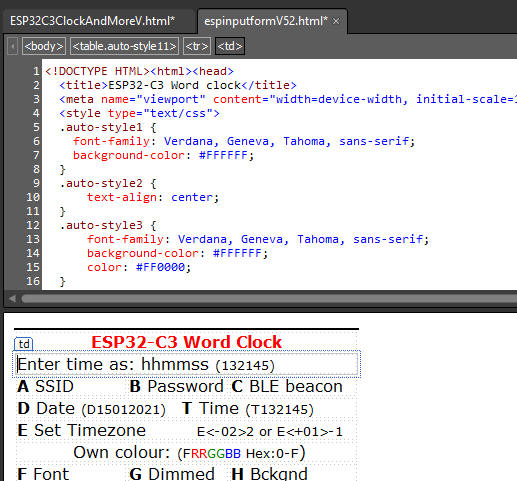
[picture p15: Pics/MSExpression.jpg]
MS expression
<br class="auto-style10" />
<span class="auto-style10">&nbsp;</span></p>
<p><span class="auto-style10">A long list if definitions and initialisations follows.</span><br class="auto-style10" />
<span class="auto-style10">I am not a fan of passing all the variables to and from functions and like to 
keep them global in one program list.</span><br class="auto-style10" />
<span class="auto-style10">If you write a program with other people it is good practice not to use 
too many globals 
but this program is in one large listing, for the same reason to keep it simple.</span><br class="auto-style10" />
<span class="auto-style10">I grouped all the variables per application to keep track where they are used.</span><br class="auto-style10" />
<span class="auto-style10">With a simple find it is easy in this one great listing to find the back.<br />
<br />
To print the time as text and colour with the proper LEDs or characters, the 
words and its position in a string of LEDs or text are defined. <br />
The defines executes the function ColorLeds with its proper parameters.<br />
Further in the program&nbsp; in the function void Dutch(void), void 
English(void) et cetera it becomes clear why these defines are so useful and 
handy.&nbsp; </span>
</p>
<pre><span class="auto-style10">...   
</span><span class="auto-style11">#define PRECIES ColorLeds("precies", 16, 22, LetterColor);
#define MTIEN   ColorLeds("tien", 25, 28, LetterColor); 
#define KWART   ColorLeds("kwart", 32, 36, LetterColor); 
#define VOOR    ColorLeds("voor", 38, 41, LetterColor); 
...</span>
</pre>
<span class="auto-style10">This is the initialisation of the storage area to 
store the struct EEPROMstorage.<br />
The Struct with all its settings is saved in one command to permanent memory or 
SD</span><br class="auto-style10" />
<span class="auto-style11">Preferences FLASHSTOR;</span><br />
<br />

<span class="auto-style11">struct EEPROMstorage { // Data storage in EEPROM to maintain them after power loss</span><br />
<span class="auto-style11">byte DisplayChoice = 0;</span><br />
<span class="auto-style11">...</span><br />
<span class="auto-style11">char BLEbroadcastName[30]; // Name of the BLE beacon</span><br />
<span class="auto-style11">char Timezone[50];</span><br />
<span class="auto-style11">int Checksum = 0;</span><br />
<span class="auto-style11">} Mem;</span><br />
<br /><br />
<br /><span class="auto-style10">The variables are adressed with a short name Mem.
</span><br /><span class="auto-style10">For example Mem.DisplayChoice = 3;</span><br />
<br />
<span class="auto-style10">The Struct <span class="auto-style11">EEPROMstorage<br />
</span>is stored in the function StoreStructInFlashMemory <br />and retrieved in the function GetStructFromFlashMemory</span><br />
<br />
<br /><br />
<span class="auto-style10">The menu displayed in the serial monitor and BLE app is defined here.<br />String may not be longer than 40 characters what can be checked with the 'ruler'
<br />
string.</span><br class="auto-style10" />
<pre><span class="auto-style11">// Menu</span>
<span class="auto-style11">//0        1         2         3         4</span>
<span class="auto-style11">//1234567890123456789012345678901234567890 </span>
<span class="auto-style11">char menu[][40] = {</span>
<span class="auto-style11">"A SSID B Password C BLE beacon name",</span>
<span class="auto-style11">"D Date (D15012021) T Time (T132145)",</span>
<span class="auto-style11">...</span>
<span class="auto-style11">"W=WIFI, X=NTP, Y=BLE, Z=Fast BLE", </span>
<span class="auto-style11">"Nov 2022" };</span></pre>
<span class="auto-style10">The Setup happens here:</span><pre><span class="auto-style11">//--------------------------------------------</span>
<span class="auto-style11">// ESP32-C3 Setup</span>
<span class="auto-style11">//--------------------------------------------</span>
<span class="auto-style11">void setup() </span>
{
<span class="auto-style11">Serial.begin(115200); Tekstprintln("Serial started"); // Setup the serial port to 115200 baud //</span>
<span class="auto-style11">...
...</span>
<span class="auto-style11">msTick = LastButtonTime = millis(); </span>
}</pre>
<span class="auto-style10"><br />
The loop is kept almost empty and the program starts 
in Every SeccondCheck.<br />
There is nothing in this program that should be executes every millisecond or 
less</span><pre><span class="auto-style11">//--------------------------------------------</span>
<span class="auto-style11">// ESP32-C3 Loop</span>
<span class="auto-style11">//--------------------------------------------</span>
<span class="auto-style11">void loop() </span>
{
<span class="auto-style11">EverySecondCheck();
} </span></pre>
<span class="auto-style10">The following routines check if 
something must happen every second, minute, hour and day.<br />
This flow handling of the program keeps the processor for 99% free for other 
uses.<br />
In this program that is almost nothing but for other purposes this can be 
needed.<br />
Use delays very sparsely. <br />
In the Bluetooth and Serial communication functions some short delays are used 
that are essential <br />
here but the program only runs here when there is an actual&nbsp; communication.<br />
(An alternative method could have been the use of an interrupt every second and 
an empty loop)<br />
<br />
Writing or reading to ports consumes a lot of processor time<br />
To let the LEDs flash like a heartbeat.<br />
With %100==0 the port is written every 100 msec.<br />
The LEDs are very bright therefore only a maximum of 12 bits of the 255 are send 
to the LED.</span>

<pre><span class="auto-style11">//--------------------------------------------</span>
<span class="auto-style11">// CLOCK Update routine done every second</span>
<span class="auto-style11">//--------------------------------------------</span>
<span class="auto-style11">void EverySecondCheck(void)</span>
{
<span class="auto-style11">static int lumi=0;
(msLeap&gt;500?lumi=(1000-msLeap)/40:lumi=msLeap/40);                       
if (msLeap%100==0){ SetStatusLED(-1,-1,12-lumi,lumi*WIFIConnected,-1); } </span>
<span class="auto-style11">... </span>
<span class="auto-style11">if (timeinfo.tm_min != lastminute) EveryMinuteUpdate(); // Enter the every minute routine after one minute</span>
<span class="auto-style11">...</span>
}
<span class="auto-style11">//--------------------------------------------</span>
<span class="auto-style11">// CLOCK Update routine done every minute</span>
<span class="auto-style11">//-------------------------------------------- </span>
<span class="auto-style11">void EveryMinuteUpdate(void)</span>
{
<span class="auto-style11">...</span>
<span class="auto-style11">if(timeinfo.tm_hour != lasthour) EveryHourUpdate();</span>
}
<span class="auto-style11">//--------------------------------------------</span>
<span class="auto-style11">// CLOCK Update routine done every hour</span>
<span class="auto-style11">//--------------------------------------------</span>
<span class="auto-style11">void EveryHourUpdate(void)</span>
{
<span class="auto-style11">...</span>
<span class="auto-style11">if (timeinfo.tm_mday != lastday) EveryDayUpdate(); </span>
}
<span class="auto-style11">// //</span>
<span class="auto-style11">//------------------------------------------------------------------------------</span>
<span class="auto-style11">// CLOCK Update routine done every day</span>
<span class="auto-style11">//------------------------------------------------------------------------------</span>
<span class="auto-style11">void EveryDayUpdate(void)</span>
{
<span class="auto-style11">...</span>
}</pre>
<br class="auto-style10" />
<span class="auto-style10">Check for serial input from the serial monitor and 
pass the command to ReworkInputString()&nbsp; </span>
<pre><span class="auto-style11">//--------------------------------------------</span>
<span class="auto-style11">// Common check for serial input</span>
<span class="auto-style11">//--------------------------------------------</span>
<span class="auto-style11">void SerialCheck(void)</span>
{
<span class="auto-style11">...</span>
<span class="auto-style11">ReworkInputString(SerialString+"\n"); // Rework ReworkInputString();</span>
<span class="auto-style11">...</span>
}</pre>
<br class="auto-style10" /><span class="auto-style10">Restore all the default 
values.</span><pre><span class="auto-style11">//------------------------------------------------------------------------------</span>
<span class="auto-style11">// Common Reset to default settings</span>
<span class="auto-style11">//------------------------------------------------------------------------------</span>
<span class="auto-style11">void Reset(void)</span>
{
<span class="auto-style11">Mem.Checksum = 25065;
...
</span>}</pre>
<span class="auto-style10">Common common print routines.<br />
To keep all the print commands in one places it is easy to change these routines 
for other boards with a different 'slang'.</span><br class="auto-style10" />
<pre><span class="auto-style11">//--------------------------------------------</span>
<span class="auto-style11">// Common common print routines</span>
<span class="auto-style11">//--------------------------------------------</span>
<span class="auto-style11">void Tekstprint(char const tekst[]) { if(Serial) Serial.print(tekst); SendMessageBLE(tekst);sptext[0]=0; } </span>
<span class="auto-style11">void Tekstprintln(char const tekst[]) { sprintf(sptext,"%s\n",tekst); Tekstprint(sptext); }</span>
<span class="auto-style11">void TekstSprint(char const tekst[]) { printf(tekst); sptext[0]=0;} // printing for Debugging purposes in serial monitor </span>
<span class="auto-style11">void TekstSprintln(char const tekst[]){ sprintf(sptext,"%s\n",tekst); TekstSprint(sptext); }</span>
<span class="auto-style11">//------------------------------------------------------------------------------</span>
<span class="auto-style11">// Common Constrain a string with integers</span>
<span class="auto-style11">// The value between the first and last character in a string is returned between the low and up bounderies</span>
<span class="auto-style11">//------------------------------------------------------------------------------</span>
<span class="auto-style11">int SConstrainInt(String s,byte first,byte last,int low,int up){return constrain(s.substring(first, last).toInt(), low, up);}</span>
<span class="auto-style11">int SConstrainInt(String s,byte first, int low,int up){return constrain(s.substring(first).toInt(), low, up);}</span>

</pre>
<span class="auto-style10">The setup of storage space and control of the 
validity of the settings.<br />
In the checksum is invalid a reset() will restore the default settings</span><pre><span class="auto-style11">//--------------------------------------------</span>
<span class="auto-style11">// Common Init and check contents of EEPROM</span>
<span class="auto-style11">//--------------------------------------------</span>
<span class="auto-style11">void InitStorage(void)</span></pre>
<span class="auto-style10">Store and retrieve the settings from SPIFFS or SD or 
EEPROM<br />
the several possibilities are store here. EEPROM becomes outdated but still 
works.</span><pre><span class="auto-style11">--------------------------------------------</span>
<span class="auto-style11">// COMMON Store mem.struct in FlashStorage or SD</span>
<span class="auto-style11">//--------------------------------------------</span>
<span class="auto-style11">void StoreStructInFlashMemory(void)</span>
{
}
<span class="auto-style11">//--------------------------------------------</span>
<span class="auto-style11">// COMMON Get data from FlashStorage Preferences.h</span>
<span class="auto-style11">//--------------------------------------------</span>
<span class="auto-style11">void GetStructFromFlashMemory(void)</span>
{
}</pre>
<span class="auto-style10">Get the commands from the strings entered in the 
serial monitor, Bluetooth or the webpage<br />
and perform the command in an action.<br />
The menu letters are almost used but it possible to distinguish between lower 
and uppercase when more commands are needed.<br />
(That is why there is no conversion to UpperCase or LowerCase).</span><pre><span class="auto-style11">/--------------------------------------------</span>
<span class="auto-style11">// CLOCK Input from Bluetooth or Serial</span>
<span class="auto-style11">//--------------------------------------------</span>
<span class="auto-style11">void ReworkInputString(String InputString)</span>
{
<span class="auto-style11">.... </span>
<span class="auto-style11">switch (InputString[0])</span>
{
<span class="auto-style11">case 'A':</span>
<span class="auto-style11">case 'a': </span>
<span class="auto-style11">if (InputString.length() &gt;5 )</span>
<span class="auto-style11">...</span></pre>
<span class="auto-style10">Read the LDR and divide it with 16 to get the values 
from 0 - 4096 between 0 and 255.<br />
Not all boards has a 12 bit AD converter like. </span>
<pre><span class="auto-style11">//--------------------------------------------</span>
<span class="auto-style11">// LDR reading are between 0 and 255. </span>
<span class="auto-style11">// ESP32 analogue read is between 0 - 4096 --   is: 4096 / 8</span>
<span class="auto-style11">//--------------------------------------------</span>
<span class="auto-style11">int ReadLDR(void) {  return analogRead(PhotoCellPin)/16;}</span></pre>
<br />
<span class="auto-style10">Control the color and intensity of the LED on the 
boards in one command</span><br class="auto-style10" />
<span class="auto-style10">-1 leaves the LED unchanged. Values between 0 and 
255.</span><pre>//--------------------------------------------
<span class="auto-style11">// CLOCK Control the LEDs on the ESP32</span>
<span class="auto-style11">// -1 leaves intensity untouched</span>
<span class="auto-style11">//--------------------------------------------</span>
<span class="auto-style11">void SetStatusLED(int WW, int CW, int Re, int Gr, int Bl)</span>
{</pre>
<br />
<span class="auto-style10">This function reads the analog port and calculates an 
output intensity to a 
display or LED-strip<br />
The readings are squared to get a hyperbolic curve that resembles you eye 
correction for dark and light better than a linear range<br />
It works wonderfully well.<br />
</span><br class="auto-style10" />
<pre><span class="auto-style11">//--------------------------------------------</span> <span class="auto-style11">
// LED Dim the leds measured by the LDR and print values</span> <span class="auto-style11">
// LDR reading are between 0 and 255. The Brightness send to the LEDs is between 0 and 255</span> <span class="auto-style11">
//--------------------------------------------</span> <span class="auto-style11">
void DimLeds(bool print) { ... } </pre>
</span><span class="auto-style10"><br />
Here we print and colour the characters in the 
display or light up to proper LEDs in a String of RGB(W) LEDs.<br />
The #define executes this functions with the proper parameters for every 
language and prints the texts in the serial connections.</span><span class="auto-style11"><br />
#define QUARTER ColorLeds("quarter", 32, 38, 
LetterColor);
</span><span class="auto-style10">
<br />
<pre><span class="auto-style11">//--------------------------------------------</span></span> <span class="auto-style10">/</span>
<span class="auto-style10"><span class="auto-style11">/ LED Set color for LED. 
//--------------------------------------------</span></span> 
<span class="auto-style11">void ColorLeds(char const *Texkst, int FirstLed, int LastLed, uint32_t RGBColor)</span> 
<span class="auto-style11">{ </span>}<span class="auto-style10"></pre>
<br />
To convert all characters to uppercase in a character array.<pre><span class="auto-style11">//--------------------------------------------</span>
<span class="auto-style11">// COMMON String upper</span>
<span class="auto-style11">//--------------------------------------------</span>
<span class="auto-style11">void to_upper(char* string)</span></pre>
<pre>
Every display or strip uses other commands to regulate the brightness
Therefore for all LED/Display commands a function </pre>
<pre>//------------------------------------------------------------------------------ 
// LED Set brightness of backlight 
//------------------------------------------------------------------------------ 
void SetBrightnessLeds(byte Bright) 
{ 
 SetBackLight(Bright); // Set brightness of LEDs 
} 
</pre>
<br />
A place to turn off all LEDs or clear the display<br />
<pre><span class="auto-style11">/--------------------------------------------</span>
<span class="auto-style11">// LED Clear the character string</span>
<span class="auto-style11">//--------------------------------------------</span>
<span class="auto-style11">void LedsOff(void) </span>
</pre>
<br class="auto-style10" />
<br class="auto-style10" />
Here are all the colours are set for the characters are set.<br />
The function has changed often and it's name describes it's original purpose<br />
For backward compatibility it's name is unchanged.<br />
</span><span class="auto-style11">/--------------------------------------------</span><span class="auto-style10"><br class="auto-style11" />
<span class="auto-style11">// LED Set second color</span><br class="auto-style11" />
<span class="auto-style11">//--------------------------------------------</span><br class="auto-style11" />
<span class="auto-style11">void SetSecondColour(void)</span><br class="auto-style11" />
<span class="auto-style11">{ &nbsp;switch (Mem.DisplayChoice) &nbsp; { &nbsp;case 
DEFAULTCOLOUR: LetterColor = C_YELLOW; </span>
<br class="auto-style11" />
<span class="auto-style11">...</span><br />
<br />
<br />
SWversion() prints the menu and the settings of sevaral preferences<br />
The function has changed often and it's name describes it's original purpose<br />
For backward compatibility it's name is unchanged.<br />
PrintLine() prints the horizontal lines in the menu.<br class="auto-style10" />
<pre><span class="auto-style11">//--------------------------------------------</span>
<span class="auto-style11">// CLOCK Version and preferences info</span>
<span class="auto-style11">//--------------------------------------------</span>
<span class="auto-style11">void SWversion(void) </span>
<span class="auto-style11">{ </span>
<span class="auto-style11">#define FILENAAM (strrchr(__FILE__, '\\') ? strrchr(__FILE__, '\\') + 1 : __FILE__)</span>
<span class="auto-style11">PrintLine(35);</span>
<span class="auto-style11">for (uint8_t i = 0; i &lt; sizeof(menu) / sizeof(menu[0]); Tekstprintln(menu[i++]));</span>
<span class="auto-style11">...</span>
<span class="auto-style11">PrintLine(35);</span>
}

<span class="auto-style11">void PrintLine(byte Lengte)</span>
<span class="auto-style11">{... }</span></pre>
<br class="auto-style10" />
Displaytime() prints the time to the serial monitor as text and control wiich 
language is printed.<br />
It also sends the appropriate sequence of colour and intensities to a RGB(W) LED 
strip.</span><pre><span class="auto-style11">//--------------------------------------------</span><span class="auto-style10">
<span class="auto-style11">// CLOCK Say the time and load the LEDs </span>
<span class="auto-style11">// with the proper colour and intensity</span>
<span class="auto-style11">//--------------------------------------------</span>
<span class="auto-style11">void Displaytime(void)</span>
<span class="auto-style11">{ </span>
<span class="auto-style11">..</span>
<span class="auto-style11">switch(Language) // Print all the character in the backgound color, a sort of ClearScreen</span>
{
<span class="auto-style11">case 0: </span>
<span class="auto-style11">strncpy(Template,"HETVISOWASOVIJFQPRECIESZSTIENKPFKWARTSVOORSOVERAHALFSMIDDERTVIJFATWEESOEENOXVIERELFQTIENKTWAALFBHDRIECNEGENACHTFZESVZEVENOENVUUR",129); </span>
<span class="auto-style11">ColorLeds(Template,0,127, Mem.DimmedLetter);</span>
<span class="auto-style11">Dutch(); Print_tijd(); break;</span>
<span class="auto-style11">case 1: </span>
<span class="auto-style11">...</span>
}</pre>
<br />
A series of functions to get and store time.<br />
The NTP time server puts the retrieved time in the standard C time structures.<br />
<pre><span class="auto-style11">/--------------------------- Time functions --------------------------</span>

<span class="auto-style11">void GetTijd(byte printit)</span>
<span class="auto-style11">void Print_RTC_tijd(void)</span>
<span class="auto-style11">void PrintNTP_tijd(void)</span>
<span class="auto-style11">void PrintUTCtijd(void)</span>
<span class="auto-style11">void Print_tijd(void)</span>
<span class="auto-style11">void SetRTCTime(void)</span>

</pre>
Convert a HEX string to a unsigned 32-bits integer<br />
<pre>/--------------------------------------------
<span class="auto-style10">// CLOCK Convert Hex to uint32</span>
<span class="auto-style10">//--------------------------------------------</span>
<span class="auto-style10">uint32_t HexToDec(String hexString) </span></pre>
<h2>Functions to let the clocks speak the time in four languages</h2>
There is also a lot of slang in languages. <br />
'Half nine' sometimes means 8:30 but can also be 9:30. (-:<br />
<br />
</span><span class="auto-style11">/--------------------------------------------</span><span class="auto-style10"><br class="auto-style11" />
<span class="auto-style11">// CLOCK Dutch clock display</span><br class="auto-style11" />
<span class="auto-style11">//--------------------------------------------</span><br class="auto-style11" />
<span class="auto-style11">void Dutch(void)</span><br class="auto-style11" />
{<br class="auto-style11" />
<span class="auto-style11">HET; // HET is always on</span><br class="auto-style11" />
<span class="auto-style11">switch (timeinfo.tm_min)</span><br class="auto-style11" />
{<br class="auto-style11" />
<span class="auto-style11">case 0: IS; PRECIES; break;</span><br class="auto-style11" />
<span class="auto-style11">case 1: IS; break;</span><br class="auto-style11" />
<span class="auto-style11">case 2: </span> <br class="auto-style11" />
<span class="auto-style11">case 3: WAS; break;</span><br class="auto-style11" />
<span class="auto-style11">case 4: </span> <br class="auto-style11" />
<span class="auto-style11">case 5: </span> <br class="auto-style11" />
<span class="auto-style11">...</span><br class="auto-style11" />
<br class="auto-style11" />
<span class="auto-style11">void English(void)</span><br class="auto-style11" />
<span class="auto-style11">void German(void)</span><br class="auto-style11" />
<span class="auto-style11">void French(void)</span><br class="auto-style10" />
<br class="auto-style10" />
<br />
The Bluetooth Low Energy Nordic nRF.. functions.<br />
They are different from the Texas instrument CC2540/CC2541 that is used in other 
chipsets like the HM-10, HM16, JDY-08 et cetera.<br />
<a href="https://www.instructables.com/Communicate-Using-CC254x-or-NRF-BLE-With-Arduino-a/">More here on Instructables</a><br />
<br />
<pre><span class="auto-style11">/-----------------------------</span>
<span class="auto-style11">// BLE SendMessage by BLE Slow in packets of 20 chars</span>
<span class="auto-style11">//------------------------------</span>
<span class="auto-style11">void SendMessageBLE(std::string Message)</span>

<span class="auto-style11">/-----------------------------</span>
<span class="auto-style11">// BLE Start BLE Classes</span>
<span class="auto-style11">//------------------------------</span>
<span class="auto-style11">class MyServerCallbacks: public BLEServerCallbacks </span>

<span class="auto-style11">/-----------------------------</span>
<span class="auto-style11">// BLE Start BLE Service</span>
<span class="auto-style11">//------------------------------</span>
<span class="auto-style11">void StartBLEService(void)</span>

<span class="auto-style11">/-----------------------------</span>
<span class="auto-style11">// BLE CheckBLE</span>
<span class="auto-style11">//------------------------------</span>
<span class="auto-style11">void CheckBLE(void)</span></pre>
<br class="auto-style10" />
Functions to start a WIFI connection and use the webpage<br />
<br />
<pre><span class="auto-style11">/--------------------------------------------</span>
<span class="auto-style11">// WIFI WEBPAGE </span>
<span class="auto-style11">//--------------------------------------------</span>
<span class="auto-style11">void StartWIFI_NTP(void)</span>

<span class="auto-style11">/--------------------------------------------</span>
<span class="auto-style11">// WIFI WEBPAGE </span>
<span class="auto-style11">//--------------------------------------------</span>
<span class="auto-style11">void WebPage(void) </span>

<span class="auto-style11">/--------------------------------------------</span>
<span class="auto-style11">// WIFI WEBPAGE Not found message</span>
<span class="auto-style11">//--------------------------------------------</span>
<span class="auto-style11">void notFound(AsyncWebServerRequest *request)</span>
</pre>
<br />
<br />
<p class="auto-style10">@Ed Nieuwenhuys, May 2023&nbsp;</p>
<p class="auto-style10">&nbsp;</p>
<h2><span class="auto-style10"><strong>Time zones</strong> </span> </h2>
<p> 
<br class="auto-style10" />
<span class="auto-style10">Copy the text <strong>between the quotes </strong>and paste them after the character E 
</span> </p>

<pre><span class="auto-style10">Africa/Abidjan,"GMT0"</span>
<span class="auto-style10">Africa/Accra,"GMT0"</span>
<span class="auto-style10">Africa/Addis_Ababa,"EAT-3"</span>
<span class="auto-style10">Africa/Algiers,"CET-1"</span>
<span class="auto-style10">Africa/Asmara,"EAT-3"</span>
<span class="auto-style10">Africa/Bamako,"GMT0"</span>
<span class="auto-style10">Africa/Bangui,"WAT-1"</span>
<span class="auto-style10">Africa/Banjul,"GMT0"</span>
<span class="auto-style10">Africa/Bissau,"GMT0"</span>
<span class="auto-style10">Africa/Blantyre,"CAT-2"</span>
<span class="auto-style10">Africa/Brazzaville,"WAT-1"</span>
<span class="auto-style10">Africa/Bujumbura,"CAT-2"</span>
<span class="auto-style10">Africa/Cairo,"EET-2"</span>
<span class="auto-style10">Africa/Casablanca,"&lt;+01&gt;-1"</span>
<span class="auto-style10">Africa/Ceuta,"CET-1CEST,M3.5.0,M10.5.0/3"</span>
<span class="auto-style10">Africa/Conakry,"GMT0"</span>
<span class="auto-style10">Africa/Dakar,"GMT0"</span>
<span class="auto-style10">Africa/Dar_es_Salaam,"EAT-3"</span>
<span class="auto-style10">Africa/Djibouti,"EAT-3"</span>
<span class="auto-style10">Africa/Douala,"WAT-1"</span>
<span class="auto-style10">Africa/El_Aaiun,"&lt;+01&gt;-1"</span>
<span class="auto-style10">Africa/Freetown,"GMT0"</span>
<span class="auto-style10">Africa/Gaborone,"CAT-2"</span>
<span class="auto-style10">Africa/Harare,"CAT-2"</span>
<span class="auto-style10">Africa/Johannesburg,"SAST-2"</span>
<span class="auto-style10">Africa/Juba,"CAT-2"</span>
<span class="auto-style10">Africa/Kampala,"EAT-3"</span>
<span class="auto-style10">Africa/Khartoum,"CAT-2"</span>
<span class="auto-style10">Africa/Kigali,"CAT-2"</span>
<span class="auto-style10">Africa/Kinshasa,"WAT-1"</span>
<span class="auto-style10">Africa/Lagos,"WAT-1"</span>
<span class="auto-style10">Africa/Libreville,"WAT-1"</span>
<span class="auto-style10">Africa/Lome,"GMT0"</span>
<span class="auto-style10">Africa/Luanda,"WAT-1"</span>
<span class="auto-style10">Africa/Lubumbashi,"CAT-2"</span>
<span class="auto-style10">Africa/Lusaka,"CAT-2"</span>
<span class="auto-style10">Africa/Malabo,"WAT-1"</span>
<span class="auto-style10">Africa/Maputo,"CAT-2"</span>
<span class="auto-style10">Africa/Maseru,"SAST-2"</span>
<span class="auto-style10">Africa/Mbabane,"SAST-2"</span>
<span class="auto-style10">Africa/Mogadishu,"EAT-3"</span>
<span class="auto-style10">Africa/Monrovia,"GMT0"</span>
<span class="auto-style10">Africa/Nairobi,"EAT-3"</span>
<span class="auto-style10">Africa/Ndjamena,"WAT-1"</span>
<span class="auto-style10">Africa/Niamey,"WAT-1"</span>
<span class="auto-style10">Africa/Nouakchott,"GMT0"</span>
<span class="auto-style10">Africa/Ouagadougou,"GMT0"</span>
<span class="auto-style10">Africa/Porto-Novo,"WAT-1"</span>
<span class="auto-style10">Africa/Sao_Tome,"GMT0"</span>
<span class="auto-style10">Africa/Tripoli,"EET-2"</span>
<span class="auto-style10">Africa/Tunis,"CET-1"</span>
<span class="auto-style10">Africa/Windhoek,"CAT-2"</span>
<span class="auto-style10">America/Adak,"HST10HDT,M3.2.0,M11.1.0"</span>
<span class="auto-style10">America/Anchorage,"AKST9AKDT,M3.2.0,M11.1.0"</span>
<span class="auto-style10">America/Anguilla,"AST4"</span>
<span class="auto-style10">America/Antigua,"AST4"</span>
<span class="auto-style10">America/Araguaina,"&lt;-03&gt;3"</span>
<span class="auto-style10">America/Argentina/Buenos_Aires,"&lt;-03&gt;3"</span>
<span class="auto-style10">America/Argentina/Catamarca,"&lt;-03&gt;3"</span>
<span class="auto-style10">America/Argentina/Cordoba,"&lt;-03&gt;3"</span>
<span class="auto-style10">America/Argentina/Jujuy,"&lt;-03&gt;3"</span>
<span class="auto-style10">America/Argentina/La_Rioja,"&lt;-03&gt;3"</span>
<span class="auto-style10">America/Argentina/Mendoza,"&lt;-03&gt;3"</span>
<span class="auto-style10">America/Argentina/Rio_Gallegos,"&lt;-03&gt;3"</span>
<span class="auto-style10">America/Argentina/Salta,"&lt;-03&gt;3"</span>
<span class="auto-style10">America/Argentina/San_Juan,"&lt;-03&gt;3"</span>
<span class="auto-style10">America/Argentina/San_Luis,"&lt;-03&gt;3"</span>
<span class="auto-style10">America/Argentina/Tucuman,"&lt;-03&gt;3"</span>
<span class="auto-style10">America/Argentina/Ushuaia,"&lt;-03&gt;3"</span>
<span class="auto-style10">America/Aruba,"AST4"</span>
<span class="auto-style10">America/Asuncion,"&lt;-04&gt;4&lt;-03&gt;,M10.1.0/0,M3.4.0/0"</span>
<span class="auto-style10">America/Atikokan,"EST5"</span>
<span class="auto-style10">America/Bahia,"&lt;-03&gt;3"</span>
<span class="auto-style10">America/Bahia_Banderas,"CST6CDT,M4.1.0,M10.5.0"</span>
<span class="auto-style10">America/Barbados,"AST4"</span>
<span class="auto-style10">America/Belem,"&lt;-03&gt;3"</span>
<span class="auto-style10">America/Belize,"CST6"</span>
<span class="auto-style10">America/Blanc-Sablon,"AST4"</span>
<span class="auto-style10">America/Boa_Vista,"&lt;-04&gt;4"</span>
<span class="auto-style10">America/Bogota,"&lt;-05&gt;5"</span>
<span class="auto-style10">America/Boise,"MST7MDT,M3.2.0,M11.1.0"</span>
<span class="auto-style10">America/Cambridge_Bay,"MST7MDT,M3.2.0,M11.1.0"</span>
<span class="auto-style10">America/Campo_Grande,"&lt;-04&gt;4"</span>
<span class="auto-style10">America/Cancun,"EST5"</span>
<span class="auto-style10">America/Caracas,"&lt;-04&gt;4"</span>
<span class="auto-style10">America/Cayenne,"&lt;-03&gt;3"</span>
<span class="auto-style10">America/Cayman,"EST5"</span>
<span class="auto-style10">America/Chicago,"CST6CDT,M3.2.0,M11.1.0"</span>
<span class="auto-style10">America/Chihuahua,"MST7MDT,M4.1.0,M10.5.0"</span>
<span class="auto-style10">America/Costa_Rica,"CST6"</span>
<span class="auto-style10">America/Creston,"MST7"</span>
<span class="auto-style10">America/Cuiaba,"&lt;-04&gt;4"</span>
<span class="auto-style10">America/Curacao,"AST4"</span>
<span class="auto-style10">America/Danmarkshavn,"GMT0"</span>
<span class="auto-style10">America/Dawson,"MST7"</span>
<span class="auto-style10">America/Dawson_Creek,"MST7"</span>
<span class="auto-style10">America/Denver,"MST7MDT,M3.2.0,M11.1.0"</span>
<span class="auto-style10">America/Detroit,"EST5EDT,M3.2.0,M11.1.0"</span>
<span class="auto-style10">America/Dominica,"AST4"</span>
<span class="auto-style10">America/Edmonton,"MST7MDT,M3.2.0,M11.1.0"</span>
<span class="auto-style10">America/Eirunepe,"&lt;-05&gt;5"</span>
<span class="auto-style10">America/El_Salvador,"CST6"</span>
<span class="auto-style10">America/Fortaleza,"&lt;-03&gt;3"</span>
<span class="auto-style10">America/Fort_Nelson,"MST7"</span>
<span class="auto-style10">America/Glace_Bay,"AST4ADT,M3.2.0,M11.1.0"</span>
<span class="auto-style10">America/Godthab,"&lt;-03&gt;3&lt;-02&gt;,M3.5.0/-2,M10.5.0/-1"</span>
<span class="auto-style10">America/Goose_Bay,"AST4ADT,M3.2.0,M11.1.0"</span>
<span class="auto-style10">America/Grand_Turk,"EST5EDT,M3.2.0,M11.1.0"</span>
<span class="auto-style10">America/Grenada,"AST4"</span>
<span class="auto-style10">America/Guadeloupe,"AST4"</span>
<span class="auto-style10">America/Guatemala,"CST6"</span>
<span class="auto-style10">America/Guayaquil,"&lt;-05&gt;5"</span>
<span class="auto-style10">America/Guyana,"&lt;-04&gt;4"</span>
<span class="auto-style10">America/Halifax,"AST4ADT,M3.2.0,M11.1.0"</span>
<span class="auto-style10">America/Havana,"CST5CDT,M3.2.0/0,M11.1.0/1"</span>
<span class="auto-style10">America/Hermosillo,"MST7"</span>
<span class="auto-style10">America/Indiana/Indianapolis,"EST5EDT,M3.2.0,M11.1.0"</span>
<span class="auto-style10">America/Indiana/Knox,"CST6CDT,M3.2.0,M11.1.0"</span>
<span class="auto-style10">America/Indiana/Marengo,"EST5EDT,M3.2.0,M11.1.0"</span>
<span class="auto-style10">America/Indiana/Petersburg,"EST5EDT,M3.2.0,M11.1.0"</span>
<span class="auto-style10">America/Indiana/Tell_City,"CST6CDT,M3.2.0,M11.1.0"</span>
<span class="auto-style10">America/Indiana/Vevay,"EST5EDT,M3.2.0,M11.1.0"</span>
<span class="auto-style10">America/Indiana/Vincennes,"EST5EDT,M3.2.0,M11.1.0"</span>
<span class="auto-style10">America/Indiana/Winamac,"EST5EDT,M3.2.0,M11.1.0"</span>
<span class="auto-style10">America/Inuvik,"MST7MDT,M3.2.0,M11.1.0"</span>
<span class="auto-style10">America/Iqaluit,"EST5EDT,M3.2.0,M11.1.0"</span>
<span class="auto-style10">America/Jamaica,"EST5"</span>
<span class="auto-style10">America/Juneau,"AKST9AKDT,M3.2.0,M11.1.0"</span>
<span class="auto-style10">America/Kentucky/Louisville,"EST5EDT,M3.2.0,M11.1.0"</span>
<span class="auto-style10">America/Kentucky/Monticello,"EST5EDT,M3.2.0,M11.1.0"</span>
<span class="auto-style10">America/Kralendijk,"AST4"</span>
<span class="auto-style10">America/La_Paz,"&lt;-04&gt;4"</span>
<span class="auto-style10">America/Lima,"&lt;-05&gt;5"</span>
<span class="auto-style10">America/Los_Angeles,"PST8PDT,M3.2.0,M11.1.0"</span>
<span class="auto-style10">America/Lower_Princes,"AST4"</span>
<span class="auto-style10">America/Maceio,"&lt;-03&gt;3"</span>
<span class="auto-style10">America/Managua,"CST6"</span>
<span class="auto-style10">America/Manaus,"&lt;-04&gt;4"</span>
<span class="auto-style10">America/Marigot,"AST4"</span>
<span class="auto-style10">America/Martinique,"AST4"</span>
<span class="auto-style10">America/Matamoros,"CST6CDT,M3.2.0,M11.1.0"</span>
<span class="auto-style10">America/Mazatlan,"MST7MDT,M4.1.0,M10.5.0"</span>
<span class="auto-style10">America/Menominee,"CST6CDT,M3.2.0,M11.1.0"</span>
<span class="auto-style10">America/Merida,"CST6CDT,M4.1.0,M10.5.0"</span>
<span class="auto-style10">America/Metlakatla,"AKST9AKDT,M3.2.0,M11.1.0"</span>
<span class="auto-style10">America/Mexico_City,"CST6CDT,M4.1.0,M10.5.0"</span>
<span class="auto-style10">America/Miquelon,"&lt;-03&gt;3&lt;-02&gt;,M3.2.0,M11.1.0"</span>
<span class="auto-style10">America/Moncton,"AST4ADT,M3.2.0,M11.1.0"</span>
<span class="auto-style10">America/Monterrey,"CST6CDT,M4.1.0,M10.5.0"</span>
<span class="auto-style10">America/Montevideo,"&lt;-03&gt;3"</span>
<span class="auto-style10">America/Montreal,"EST5EDT,M3.2.0,M11.1.0"</span>
<span class="auto-style10">America/Montserrat,"AST4"</span>
<span class="auto-style10">America/Nassau,"EST5EDT,M3.2.0,M11.1.0"</span>
<span class="auto-style10">America/New_York,"EST5EDT,M3.2.0,M11.1.0"</span>
<span class="auto-style10">America/Nipigon,"EST5EDT,M3.2.0,M11.1.0"</span>
<span class="auto-style10">America/Nome,"AKST9AKDT,M3.2.0,M11.1.0"</span>
<span class="auto-style10">America/Noronha,"&lt;-02&gt;2"</span>
<span class="auto-style10">America/North_Dakota/Beulah,"CST6CDT,M3.2.0,M11.1.0"</span>
<span class="auto-style10">America/North_Dakota/Center,"CST6CDT,M3.2.0,M11.1.0"</span>
<span class="auto-style10">America/North_Dakota/New_Salem,"CST6CDT,M3.2.0,M11.1.0"</span>
<span class="auto-style10">America/Nuuk,"&lt;-03&gt;3&lt;-02&gt;,M3.5.0/-2,M10.5.0/-1"</span>
<span class="auto-style10">America/Ojinaga,"MST7MDT,M3.2.0,M11.1.0"</span>
<span class="auto-style10">America/Panama,"EST5"</span>
<span class="auto-style10">America/Pangnirtung,"EST5EDT,M3.2.0,M11.1.0"</span>
<span class="auto-style10">America/Paramaribo,"&lt;-03&gt;3"</span>
<span class="auto-style10">America/Phoenix,"MST7"</span>
<span class="auto-style10">America/Port-au-Prince,"EST5EDT,M3.2.0,M11.1.0"</span>
<span class="auto-style10">America/Port_of_Spain,"AST4"</span>
<span class="auto-style10">America/Porto_Velho,"&lt;-04&gt;4"</span>
<span class="auto-style10">America/Puerto_Rico,"AST4"</span>
<span class="auto-style10">America/Punta_Arenas,"&lt;-03&gt;3"</span>
<span class="auto-style10">America/Rainy_River,"CST6CDT,M3.2.0,M11.1.0"</span>
<span class="auto-style10">America/Rankin_Inlet,"CST6CDT,M3.2.0,M11.1.0"</span>
<span class="auto-style10">America/Recife,"&lt;-03&gt;3"</span>
<span class="auto-style10">America/Regina,"CST6"</span>
<span class="auto-style10">America/Resolute,"CST6CDT,M3.2.0,M11.1.0"</span>
<span class="auto-style10">America/Rio_Branco,"&lt;-05&gt;5"</span>
<span class="auto-style10">America/Santarem,"&lt;-03&gt;3"</span>
<span class="auto-style10">America/Santiago,"&lt;-04&gt;4&lt;-03&gt;,M9.1.6/24,M4.1.6/24"</span>
<span class="auto-style10">America/Santo_Domingo,"AST4"</span>
<span class="auto-style10">America/Sao_Paulo,"&lt;-03&gt;3"</span>
<span class="auto-style10">America/Scoresbysund,"&lt;-01&gt;1&lt;+00&gt;,M3.5.0/0,M10.5.0/1"</span>
<span class="auto-style10">America/Sitka,"AKST9AKDT,M3.2.0,M11.1.0"</span>
<span class="auto-style10">America/St_Barthelemy,"AST4"</span>
<span class="auto-style10">America/St_Johns,"NST3:30NDT,M3.2.0,M11.1.0"</span>
<span class="auto-style10">America/St_Kitts,"AST4"</span>
<span class="auto-style10">America/St_Lucia,"AST4"</span>
<span class="auto-style10">America/St_Thomas,"AST4"</span>
<span class="auto-style10">America/St_Vincent,"AST4"</span>
<span class="auto-style10">America/Swift_Current,"CST6"</span>
<span class="auto-style10">America/Tegucigalpa,"CST6"</span>
<span class="auto-style10">America/Thule,"AST4ADT,M3.2.0,M11.1.0"</span>
<span class="auto-style10">America/Thunder_Bay,"EST5EDT,M3.2.0,M11.1.0"</span>
<span class="auto-style10">America/Tijuana,"PST8PDT,M3.2.0,M11.1.0"</span>
<span class="auto-style10">America/Toronto,"EST5EDT,M3.2.0,M11.1.0"</span>
<span class="auto-style10">America/Tortola,"AST4"</span>
<span class="auto-style10">America/Vancouver,"PST8PDT,M3.2.0,M11.1.0"</span>
<span class="auto-style10">America/Whitehorse,"MST7"</span>
<span class="auto-style10">America/Winnipeg,"CST6CDT,M3.2.0,M11.1.0"</span>
<span class="auto-style10">America/Yakutat,"AKST9AKDT,M3.2.0,M11.1.0"</span>
<span class="auto-style10">America/Yellowknife,"MST7MDT,M3.2.0,M11.1.0"</span>
<span class="auto-style10">Antarctica/Casey,"&lt;+11&gt;-11"</span>
<span class="auto-style10">Antarctica/Davis,"&lt;+07&gt;-7"</span>
<span class="auto-style10">Antarctica/DumontDUrville,"&lt;+10&gt;-10"</span>
<span class="auto-style10">Antarctica/Macquarie,"AEST-10AEDT,M10.1.0,M4.1.0/3"</span>
<span class="auto-style10">Antarctica/Mawson,"&lt;+05&gt;-5"</span>
<span class="auto-style10">Antarctica/McMurdo,"NZST-12NZDT,M9.5.0,M4.1.0/3"</span>
<span class="auto-style10">Antarctica/Palmer,"&lt;-03&gt;3"</span>
<span class="auto-style10">Antarctica/Rothera,"&lt;-03&gt;3"</span>
<span class="auto-style10">Antarctica/Syowa,"&lt;+03&gt;-3"</span>
<span class="auto-style10">Antarctica/Troll,"&lt;+00&gt;0&lt;+02&gt;-2,M3.5.0/1,M10.5.0/3"</span>
<span class="auto-style10">Antarctica/Vostok,"&lt;+06&gt;-6"</span>
<span class="auto-style10">Arctic/Longyearbyen,"CET-1CEST,M3.5.0,M10.5.0/3"</span>
<span class="auto-style10">Asia/Aden,"&lt;+03&gt;-3"</span>
<span class="auto-style10">Asia/Almaty,"&lt;+06&gt;-6"</span>
<span class="auto-style10">Asia/Amman,"EET-2EEST,M2.5.4/24,M10.5.5/1"</span>
<span class="auto-style10">Asia/Anadyr,"&lt;+12&gt;-12"</span>
<span class="auto-style10">Asia/Aqtau,"&lt;+05&gt;-5"</span>
<span class="auto-style10">Asia/Aqtobe,"&lt;+05&gt;-5"</span>
<span class="auto-style10">Asia/Ashgabat,"&lt;+05&gt;-5"</span>
<span class="auto-style10">Asia/Atyrau,"&lt;+05&gt;-5"</span>
<span class="auto-style10">Asia/Baghdad,"&lt;+03&gt;-3"</span>
<span class="auto-style10">Asia/Bahrain,"&lt;+03&gt;-3"</span>
<span class="auto-style10">Asia/Baku,"&lt;+04&gt;-4"</span>
<span class="auto-style10">Asia/Bangkok,"&lt;+07&gt;-7"</span>
<span class="auto-style10">Asia/Barnaul,"&lt;+07&gt;-7"</span>
<span class="auto-style10">Asia/Beirut,"EET-2EEST,M3.5.0/0,M10.5.0/0"</span>
<span class="auto-style10">Asia/Bishkek,"&lt;+06&gt;-6"</span>
<span class="auto-style10">Asia/Brunei,"&lt;+08&gt;-8"</span>
<span class="auto-style10">Asia/Chita,"&lt;+09&gt;-9"</span>
<span class="auto-style10">Asia/Choibalsan,"&lt;+08&gt;-8"</span>
<span class="auto-style10">Asia/Colombo,"&lt;+0530&gt;-5:30"</span>
<span class="auto-style10">Asia/Damascus,"EET-2EEST,M3.5.5/0,M10.5.5/0"</span>
<span class="auto-style10">Asia/Dhaka,"&lt;+06&gt;-6"</span>
<span class="auto-style10">Asia/Dili,"&lt;+09&gt;-9"</span>
<span class="auto-style10">Asia/Dubai,"&lt;+04&gt;-4"</span>
<span class="auto-style10">Asia/Dushanbe,"&lt;+05&gt;-5"</span>
<span class="auto-style10">Asia/Famagusta,"EET-2EEST,M3.5.0/3,M10.5.0/4"</span>
<span class="auto-style10">Asia/Gaza,"EET-2EEST,M3.4.4/48,M10.5.5/1"</span>
<span class="auto-style10">Asia/Hebron,"EET-2EEST,M3.4.4/48,M10.5.5/1"</span>
<span class="auto-style10">Asia/Ho_Chi_Minh,"&lt;+07&gt;-7"</span>
<span class="auto-style10">Asia/Hong_Kong,"HKT-8"</span>
<span class="auto-style10">Asia/Hovd,"&lt;+07&gt;-7"</span>
<span class="auto-style10">Asia/Irkutsk,"&lt;+08&gt;-8"</span>
<span class="auto-style10">Asia/Jakarta,"WIB-7"</span>
<span class="auto-style10">Asia/Jayapura,"WIT-9"</span>
<span class="auto-style10">Asia/Jerusalem,"IST-2IDT,M3.4.4/26,M10.5.0"</span>
<span class="auto-style10">Asia/Kabul,"&lt;+0430&gt;-4:30"</span>
<span class="auto-style10">Asia/Kamchatka,"&lt;+12&gt;-12"</span>
<span class="auto-style10">Asia/Karachi,"PKT-5"</span>
<span class="auto-style10">Asia/Kathmandu,"&lt;+0545&gt;-5:45"</span>
<span class="auto-style10">Asia/Khandyga,"&lt;+09&gt;-9"</span>
<span class="auto-style10">Asia/Kolkata,"IST-5:30"</span>
<span class="auto-style10">Asia/Krasnoyarsk,"&lt;+07&gt;-7"</span>
<span class="auto-style10">Asia/Kuala_Lumpur,"&lt;+08&gt;-8"</span>
<span class="auto-style10">Asia/Kuching,"&lt;+08&gt;-8"</span>
<span class="auto-style10">Asia/Kuwait,"&lt;+03&gt;-3"</span>
<span class="auto-style10">Asia/Macau,"CST-8"</span>
<span class="auto-style10">Asia/Magadan,"&lt;+11&gt;-11"</span>
<span class="auto-style10">Asia/Makassar,"WITA-8"</span>
<span class="auto-style10">Asia/Manila,"PST-8"</span>
<span class="auto-style10">Asia/Muscat,"&lt;+04&gt;-4"</span>
<span class="auto-style10">Asia/Nicosia,"EET-2EEST,M3.5.0/3,M10.5.0/4"</span>
<span class="auto-style10">Asia/Novokuznetsk,"&lt;+07&gt;-7"</span>
<span class="auto-style10">Asia/Novosibirsk,"&lt;+07&gt;-7"</span>
<span class="auto-style10">Asia/Omsk,"&lt;+06&gt;-6"</span>
<span class="auto-style10">Asia/Oral,"&lt;+05&gt;-5"</span>
<span class="auto-style10">Asia/Phnom_Penh,"&lt;+07&gt;-7"</span>
<span class="auto-style10">Asia/Pontianak,"WIB-7"</span>
<span class="auto-style10">Asia/Pyongyang,"KST-9"</span>
<span class="auto-style10">Asia/Qatar,"&lt;+03&gt;-3"</span>
<span class="auto-style10">Asia/Qyzylorda,"&lt;+05&gt;-5"</span>
<span class="auto-style10">Asia/Riyadh,"&lt;+03&gt;-3"</span>
<span class="auto-style10">Asia/Sakhalin,"&lt;+11&gt;-11"</span>
<span class="auto-style10">Asia/Samarkand,"&lt;+05&gt;-5"</span>
<span class="auto-style10">Asia/Seoul,"KST-9"</span>
<span class="auto-style10">Asia/Shanghai,"CST-8"</span>
<span class="auto-style10">Asia/Singapore,"&lt;+08&gt;-8"</span>
<span class="auto-style10">Asia/Srednekolymsk,"&lt;+11&gt;-11"</span>
<span class="auto-style10">Asia/Taipei,"CST-8"</span>
<span class="auto-style10">Asia/Tashkent,"&lt;+05&gt;-5"</span>
<span class="auto-style10">Asia/Tbilisi,"&lt;+04&gt;-4"</span>
<span class="auto-style10">Asia/Tehran,"&lt;+0330&gt;-3:30&lt;+0430&gt;,J79/24,J263/24"</span>
<span class="auto-style10">Asia/Thimphu,"&lt;+06&gt;-6"</span>
<span class="auto-style10">Asia/Tokyo,"JST-9"</span>
<span class="auto-style10">Asia/Tomsk,"&lt;+07&gt;-7"</span>
<span class="auto-style10">Asia/Ulaanbaatar,"&lt;+08&gt;-8"</span>
<span class="auto-style10">Asia/Urumqi,"&lt;+06&gt;-6"</span>
<span class="auto-style10">Asia/Ust-Nera,"&lt;+10&gt;-10"</span>
<span class="auto-style10">Asia/Vientiane,"&lt;+07&gt;-7"</span>
<span class="auto-style10">Asia/Vladivostok,"&lt;+10&gt;-10"</span>
<span class="auto-style10">Asia/Yakutsk,"&lt;+09&gt;-9"</span>
<span class="auto-style10">Asia/Yangon,"&lt;+0630&gt;-6:30"</span>
<span class="auto-style10">Asia/Yekaterinburg,"&lt;+05&gt;-5"</span>
<span class="auto-style10">Asia/Yerevan,"&lt;+04&gt;-4"</span>
<span class="auto-style10">Atlantic/Azores,"&lt;-01&gt;1&lt;+00&gt;,M3.5.0/0,M10.5.0/1"</span>
<span class="auto-style10">Atlantic/Bermuda,"AST4ADT,M3.2.0,M11.1.0"</span>
<span class="auto-style10">Atlantic/Canary,"WET0WEST,M3.5.0/1,M10.5.0"</span>
<span class="auto-style10">Atlantic/Cape_Verde,"&lt;-01&gt;1"</span>
<span class="auto-style10">Atlantic/Faroe,"WET0WEST,M3.5.0/1,M10.5.0"</span>
<span class="auto-style10">Atlantic/Madeira,"WET0WEST,M3.5.0/1,M10.5.0"</span>
<span class="auto-style10">Atlantic/Reykjavik,"GMT0"</span>
<span class="auto-style10">Atlantic/South_Georgia,"&lt;-02&gt;2"</span>
<span class="auto-style10">Atlantic/Stanley,"&lt;-03&gt;3"</span>
<span class="auto-style10">Atlantic/St_Helena,"GMT0"</span>
<span class="auto-style10">Australia/Adelaide,"ACST-9:30ACDT,M10.1.0,M4.1.0/3"</span>
<span class="auto-style10">Australia/Brisbane,"AEST-10"</span>
<span class="auto-style10">Australia/Broken_Hill,"ACST-9:30ACDT,M10.1.0,M4.1.0/3"</span>
<span class="auto-style10">Australia/Currie,"AEST-10AEDT,M10.1.0,M4.1.0/3"</span>
<span class="auto-style10">Australia/Darwin,"ACST-9:30"</span>
<span class="auto-style10">Australia/Eucla,"&lt;+0845&gt;-8:45"</span>
<span class="auto-style10">Australia/Hobart,"AEST-10AEDT,M10.1.0,M4.1.0/3"</span>
<span class="auto-style10">Australia/Lindeman,"AEST-10"</span>
<span class="auto-style10">Australia/Lord_Howe,"&lt;+1030&gt;-10:30&lt;+11&gt;-11,M10.1.0,M4.1.0"</span>
<span class="auto-style10">Australia/Melbourne,"AEST-10AEDT,M10.1.0,M4.1.0/3"</span>
<span class="auto-style10">Australia/Perth,"AWST-8"</span>
<span class="auto-style10">Australia/Sydney,"AEST-10AEDT,M10.1.0,M4.1.0/3"</span>
<span class="auto-style10">Europe/Amsterdam,"CET-1CEST,M3.5.0,M10.5.0/3"</span>
<span class="auto-style10">Europe/Andorra,"CET-1CEST,M3.5.0,M10.5.0/3"</span>
<span class="auto-style10">Europe/Astrakhan,"&lt;+04&gt;-4"</span>
<span class="auto-style10">Europe/Athens,"EET-2EEST,M3.5.0/3,M10.5.0/4"</span>
<span class="auto-style10">Europe/Belgrade,"CET-1CEST,M3.5.0,M10.5.0/3"</span>
<span class="auto-style10">Europe/Berlin,"CET-1CEST,M3.5.0,M10.5.0/3"</span>
<span class="auto-style10">Europe/Bratislava,"CET-1CEST,M3.5.0,M10.5.0/3"</span>
<span class="auto-style10">Europe/Brussels,"CET-1CEST,M3.5.0,M10.5.0/3"</span>
<span class="auto-style10">Europe/Bucharest,"EET-2EEST,M3.5.0/3,M10.5.0/4"</span>
<span class="auto-style10">Europe/Budapest,"CET-1CEST,M3.5.0,M10.5.0/3"</span>
<span class="auto-style10">Europe/Busingen,"CET-1CEST,M3.5.0,M10.5.0/3"</span>
<span class="auto-style10">Europe/Chisinau,"EET-2EEST,M3.5.0,M10.5.0/3"</span>
<span class="auto-style10">Europe/Copenhagen,"CET-1CEST,M3.5.0,M10.5.0/3"</span>
<span class="auto-style10">Europe/Dublin,"IST-1GMT0,M10.5.0,M3.5.0/1"</span>
<span class="auto-style10">Europe/Gibraltar,"CET-1CEST,M3.5.0,M10.5.0/3"</span>
<span class="auto-style10">Europe/Guernsey,"GMT0BST,M3.5.0/1,M10.5.0"</span>
<span class="auto-style10">Europe/Helsinki,"EET-2EEST,M3.5.0/3,M10.5.0/4"</span>
<span class="auto-style10">Europe/Isle_of_Man,"GMT0BST,M3.5.0/1,M10.5.0"</span>
<span class="auto-style10">Europe/Istanbul,"&lt;+03&gt;-3"</span>
<span class="auto-style10">Europe/Jersey,"GMT0BST,M3.5.0/1,M10.5.0"</span>
<span class="auto-style10">Europe/Kaliningrad,"EET-2"</span>
<span class="auto-style10">Europe/Kiev,"EET-2EEST,M3.5.0/3,M10.5.0/4"</span>
<span class="auto-style10">Europe/Kirov,"&lt;+03&gt;-3"</span>
<span class="auto-style10">Europe/Lisbon,"WET0WEST,M3.5.0/1,M10.5.0"</span>
<span class="auto-style10">Europe/Ljubljana,"CET-1CEST,M3.5.0,M10.5.0/3"</span>
<span class="auto-style10">Europe/London,"GMT0BST,M3.5.0/1,M10.5.0"</span>
<span class="auto-style10">Europe/Luxembourg,"CET-1CEST,M3.5.0,M10.5.0/3"</span>
<span class="auto-style10">Europe/Madrid,"CET-1CEST,M3.5.0,M10.5.0/3"</span>
<span class="auto-style10">Europe/Malta,"CET-1CEST,M3.5.0,M10.5.0/3"</span>
<span class="auto-style10">Europe/Mariehamn,"EET-2EEST,M3.5.0/3,M10.5.0/4"</span>
<span class="auto-style10">Europe/Minsk,"&lt;+03&gt;-3"</span>
<span class="auto-style10">Europe/Monaco,"CET-1CEST,M3.5.0,M10.5.0/3"</span>
<span class="auto-style10">Europe/Moscow,"MSK-3"</span>
<span class="auto-style10">Europe/Oslo,"CET-1CEST,M3.5.0,M10.5.0/3"</span>
<span class="auto-style10">Europe/Paris,"CET-1CEST,M3.5.0,M10.5.0/3"</span>
<span class="auto-style10">Europe/Podgorica,"CET-1CEST,M3.5.0,M10.5.0/3"</span>
<span class="auto-style10">Europe/Prague,"CET-1CEST,M3.5.0,M10.5.0/3"</span>
<span class="auto-style10">Europe/Riga,"EET-2EEST,M3.5.0/3,M10.5.0/4"</span>
<span class="auto-style10">Europe/Rome,"CET-1CEST,M3.5.0,M10.5.0/3"</span>
<span class="auto-style10">Europe/Samara,"&lt;+04&gt;-4"</span>
<span class="auto-style10">Europe/San_Marino,"CET-1CEST,M3.5.0,M10.5.0/3"</span>
<span class="auto-style10">Europe/Sarajevo,"CET-1CEST,M3.5.0,M10.5.0/3"</span>
<span class="auto-style10">Europe/Saratov,"&lt;+04&gt;-4"</span>
<span class="auto-style10">Europe/Simferopol,"MSK-3"</span>
<span class="auto-style10">Europe/Skopje,"CET-1CEST,M3.5.0,M10.5.0/3"</span>
<span class="auto-style10">Europe/Sofia,"EET-2EEST,M3.5.0/3,M10.5.0/4"</span>
<span class="auto-style10">Europe/Stockholm,"CET-1CEST,M3.5.0,M10.5.0/3"</span>
<span class="auto-style10">Europe/Tallinn,"EET-2EEST,M3.5.0/3,M10.5.0/4"</span>
<span class="auto-style10">Europe/Tirane,"CET-1CEST,M3.5.0,M10.5.0/3"</span>
<span class="auto-style10">Europe/Ulyanovsk,"&lt;+04&gt;-4"</span>
<span class="auto-style10">Europe/Uzhgorod,"EET-2EEST,M3.5.0/3,M10.5.0/4"</span>
<span class="auto-style10">Europe/Vaduz,"CET-1CEST,M3.5.0,M10.5.0/3"</span>
<span class="auto-style10">Europe/Vatican,"CET-1CEST,M3.5.0,M10.5.0/3"</span>
<span class="auto-style10">Europe/Vienna,"CET-1CEST,M3.5.0,M10.5.0/3"</span>
<span class="auto-style10">Europe/Vilnius,"EET-2EEST,M3.5.0/3,M10.5.0/4"</span>
<span class="auto-style10">Europe/Volgograd,"&lt;+03&gt;-3"</span>
<span class="auto-style10">Europe/Warsaw,"CET-1CEST,M3.5.0,M10.5.0/3"</span>
<span class="auto-style10">Europe/Zagreb,"CET-1CEST,M3.5.0,M10.5.0/3"</span>
<span class="auto-style10">Europe/Zaporozhye,"EET-2EEST,M3.5.0/3,M10.5.0/4"</span>
<span class="auto-style10">Europe/Zurich,"CET-1CEST,M3.5.0,M10.5.0/3"</span>
<span class="auto-style10">Indian/Antananarivo,"EAT-3"</span>
<span class="auto-style10">Indian/Chagos,"&lt;+06&gt;-6"</span>
<span class="auto-style10">Indian/Christmas,"&lt;+07&gt;-7"</span>
<span class="auto-style10">Indian/Cocos,"&lt;+0630&gt;-6:30"</span>
<span class="auto-style10">Indian/Comoro,"EAT-3"</span>
<span class="auto-style10">Indian/Kerguelen,"&lt;+05&gt;-5"</span>
<span class="auto-style10">Indian/Mahe,"&lt;+04&gt;-4"</span>
<span class="auto-style10">Indian/Maldives,"&lt;+05&gt;-5"</span>
<span class="auto-style10">Indian/Mauritius,"&lt;+04&gt;-4"</span>
<span class="auto-style10">Indian/Mayotte,"EAT-3"</span>
<span class="auto-style10">Indian/Reunion,"&lt;+04&gt;-4"</span>
<span class="auto-style10">Pacific/Apia,"&lt;+13&gt;-13"</span>
<span class="auto-style10">Pacific/Auckland,"NZST-12NZDT,M9.5.0,M4.1.0/3"</span>
<span class="auto-style10">Pacific/Bougainville,"&lt;+11&gt;-11"</span>
<span class="auto-style10">Pacific/Chatham,"&lt;+1245&gt;-12:45&lt;+1345&gt;,M9.5.0/2:45,M4.1.0/3:45"</span>
<span class="auto-style10">Pacific/Chuuk,"&lt;+10&gt;-10"</span>
<span class="auto-style10">Pacific/Easter,"&lt;-06&gt;6&lt;-05&gt;,M9.1.6/22,M4.1.6/22"</span>
<span class="auto-style10">Pacific/Efate,"&lt;+11&gt;-11"</span>
<span class="auto-style10">Pacific/Enderbury,"&lt;+13&gt;-13"</span>
<span class="auto-style10">Pacific/Fakaofo,"&lt;+13&gt;-13"</span>
<span class="auto-style10">Pacific/Fiji,"&lt;+12&gt;-12&lt;+13&gt;,M11.2.0,M1.2.3/99"</span>
<span class="auto-style10">Pacific/Funafuti,"&lt;+12&gt;-12"</span>
<span class="auto-style10">Pacific/Galapagos,"&lt;-06&gt;6"</span>
<span class="auto-style10">Pacific/Gambier,"&lt;-09&gt;9"</span>
<span class="auto-style10">Pacific/Guadalcanal,"&lt;+11&gt;-11"</span>
<span class="auto-style10">Pacific/Guam,"ChST-10"</span>
<span class="auto-style10">Pacific/Honolulu,"HST10"</span>
<span class="auto-style10">Pacific/Kiritimati,"&lt;+14&gt;-14"</span>
<span class="auto-style10">Pacific/Kosrae,"&lt;+11&gt;-11"</span>
<span class="auto-style10">Pacific/Kwajalein,"&lt;+12&gt;-12"</span>
<span class="auto-style10">Pacific/Majuro,"&lt;+12&gt;-12"</span>
<span class="auto-style10">Pacific/Marquesas,"&lt;-0930&gt;9:30"</span>
<span class="auto-style10">Pacific/Midway,"SST11"</span>
<span class="auto-style10">Pacific/Nauru,"&lt;+12&gt;-12"</span>
<span class="auto-style10">Pacific/Niue,"&lt;-11&gt;11"</span>
<span class="auto-style10">Pacific/Norfolk,"&lt;+11&gt;-11&lt;+12&gt;,M10.1.0,M4.1.0/3"</span>
<span class="auto-style10">Pacific/Noumea,"&lt;+11&gt;-11"</span>
<span class="auto-style10">Pacific/Pago_Pago,"SST11"</span>
<span class="auto-style10">Pacific/Palau,"&lt;+09&gt;-9"</span>
<span class="auto-style10">Pacific/Pitcairn,"&lt;-08&gt;8"</span>
<span class="auto-style10">Pacific/Pohnpei,"&lt;+11&gt;-11"</span>
<span class="auto-style10">Pacific/Port_Moresby,"&lt;+10&gt;-10"</span>
<span class="auto-style10">Pacific/Rarotonga,"&lt;-10&gt;10"</span>
<span class="auto-style10">Pacific/Saipan,"ChST-10"</span>
<span class="auto-style10">Pacific/Tahiti,"&lt;-10&gt;10"</span>
<span class="auto-style10">Pacific/Tarawa,"&lt;+12&gt;-12"</span>
<span class="auto-style10">Pacific/Tongatapu,"&lt;+13&gt;-13"</span>
<span class="auto-style10">Pacific/Wake,"&lt;+12&gt;-12"</span>
<span class="auto-style10">Pacific/Wallis,"&lt;+12&gt;-12"</span>
<span class="auto-style10">Etc/GMT,"GMT0"</span>
<span class="auto-style10">Etc/GMT-0,"GMT0"</span>
<span class="auto-style10">Etc/GMT-1,"&lt;+01&gt;-1"</span>
<span class="auto-style10">Etc/GMT-2,"&lt;+02&gt;-2"</span>
<span class="auto-style10">Etc/GMT-3,"&lt;+03&gt;-3"</span>
<span class="auto-style10">Etc/GMT-4,"&lt;+04&gt;-4"</span>
<span class="auto-style10">Etc/GMT-5,"&lt;+05&gt;-5"</span>
<span class="auto-style10">Etc/GMT-6,"&lt;+06&gt;-6"</span>
<span class="auto-style10">Etc/GMT-7,"&lt;+07&gt;-7"</span>
<span class="auto-style10">Etc/GMT-8,"&lt;+08&gt;-8"</span>
<span class="auto-style10">Etc/GMT-9,"&lt;+09&gt;-9"</span>
<span class="auto-style10">Etc/GMT-10,"&lt;+10&gt;-10"</span>
<span class="auto-style10">Etc/GMT-11,"&lt;+11&gt;-11"</span>
<span class="auto-style10">Etc/GMT-12,"&lt;+12&gt;-12"</span>
<span class="auto-style10">Etc/GMT-13,"&lt;+13&gt;-13"</span>
<span class="auto-style10">Etc/GMT-14,"&lt;+14&gt;-14"</span>
<span class="auto-style10">Etc/GMT0,"GMT0"</span>
<span class="auto-style10">Etc/GMT+0,"GMT0"</span>
<span class="auto-style10">Etc/GMT+1,"&lt;-01&gt;1"</span>
<span class="auto-style10">Etc/GMT+2,"&lt;-02&gt;2"</span>
<span class="auto-style10">Etc/GMT+3,"&lt;-03&gt;3"</span>
<span class="auto-style10">Etc/GMT+4,"&lt;-04&gt;4"</span>
<span class="auto-style10">Etc/GMT+5,"&lt;-05&gt;5"</span>
<span class="auto-style10">Etc/GMT+6,"&lt;-06&gt;6"</span>
<span class="auto-style10">Etc/GMT+7,"&lt;-07&gt;7"</span>
<span class="auto-style10">Etc/GMT+8,"&lt;-08&gt;8"</span>
<span class="auto-style10">Etc/GMT+9,"&lt;-09&gt;9"</span>
<span class="auto-style10">Etc/GMT+10,"&lt;-10&gt;10"</span>
<span class="auto-style10">Etc/GMT+11,"&lt;-11&gt;11"</span>
<span class="auto-style10">Etc/GMT+12,"&lt;-12&gt;12"</span>
<span class="auto-style10">Etc/UCT,"UTC0"</span>
<span class="auto-style10">Etc/UTC,"UTC0"</span>
<span class="auto-style10">Etc/Greenwich,"GMT0"</span>
<span class="auto-style10">Etc/Universal,"UTC0"</span>
<span class="auto-style10">Etc/Zulu,"UTC0"</span></pre>

</span>

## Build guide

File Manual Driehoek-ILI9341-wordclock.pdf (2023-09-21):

# ESP32-C3 Driehoek-ILI9341-wordclock

A clock that displays time in words in the languages Dutch, English, French and German or all four randomly.
The clock can also show time in an analogue or digital format on a ILI9341 display. Time is synchronized with the Network Time Protocol (NTP) from the internet. Settings can be controlled with a webpage, a PC or a Bluetooth Low Energy (BLE) serial terminal app installed on a phone, PC or tablet.

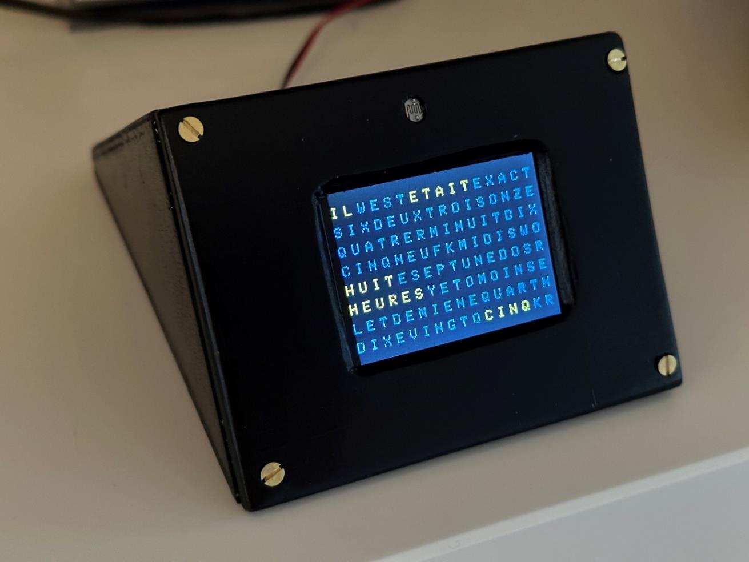
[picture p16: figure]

This clock is built with a 4 MB ESP32-C3-12F microprocessor board chip and a ILI9341 display with Espressif BLE nRF52 and WIFI.

Es war viertel nach zehn 10:17:00 It was quarter past ten 10:18:00 Il est dix heures vingt 10:19:00 Es ist zehn vor halb elf 10:20:00 Het is tien voor half elf 10:21:00 It was twenty past ten 10:22:00 It was twenty past ten 10:23:00 Het is vijf voor half elf 10:24:00 Es ist funf vor halb elf 10:25:00 It is twenty five past ten 10:26:00
Es war funf vor halb elf 10:27:00

Display of the time in the serial terminal output.

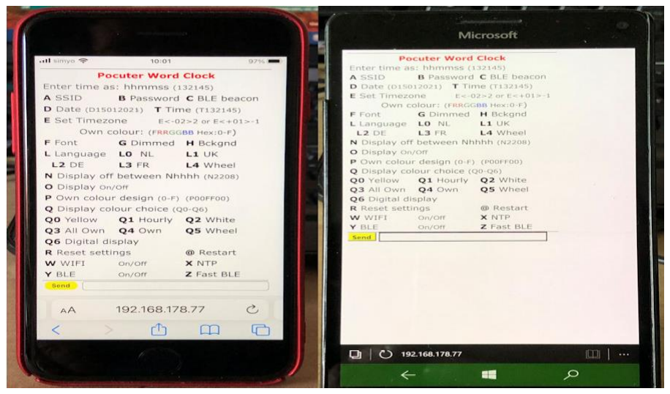
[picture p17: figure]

HTML page in iPhone 8 and Microsoft Phone

Before starting

The clock receives time from the internet. Therefore the name of the WIFI station and its password must be entered to be able to connect to a WIFI router.
The name of the WIFI-station and password has to be entered once. These credentials will be stored in memory of the MCU.
To make life easy it is preferred to use a phone and an communication app of a phone or tablet enter the WIFI credentials into the clock.

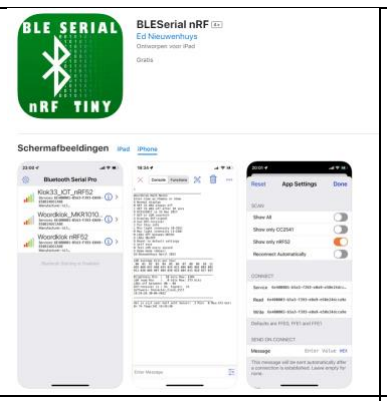
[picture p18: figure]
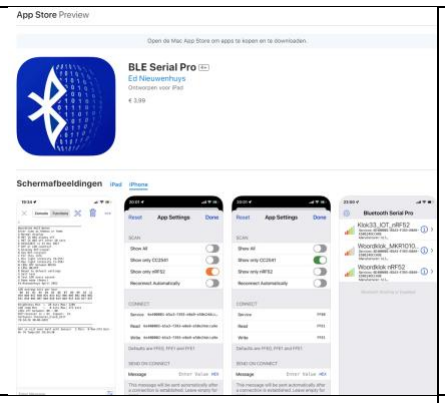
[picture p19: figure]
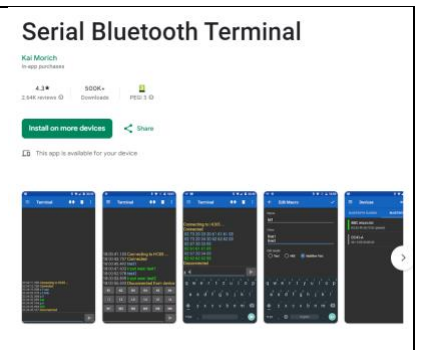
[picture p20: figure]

BLESerial nRF | BLE Serial Pro | Serial Bluetooth Terminal
- Download a Bluetooth UART serial terminal app on your phone, PC, or tablet. For IOS: BLE Serial Pro or BLESerial nRF.
For Android: Serial Bluetooth Terminal.

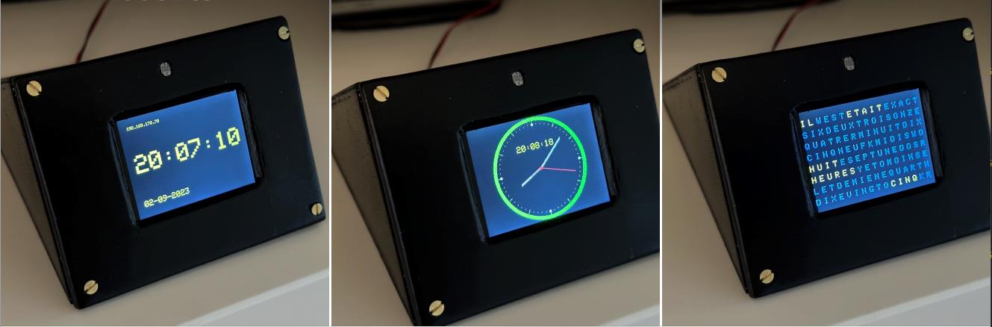
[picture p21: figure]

Installations

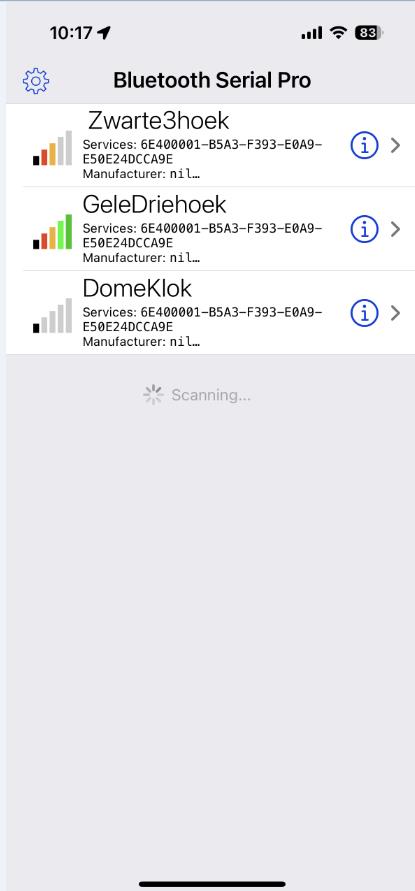
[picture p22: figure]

To connect to a WIFI network a SSID (WIFI name) and password must be entered.
There are a few methods:
Connect the MCU in the clock with a micro USB serial cable to a PC and use a serial terminal.
Use a BLE serial terminal app on a phone or tablet for connection.

For a PC the app Termite (https://www.compuphase.com/software_termite.htm) is fine as serial terminal.

For IOS use: BLE Serial Pro or BLESerial nRF.

For Android use: Serial Bluetooth terminal.

Bluetooth Low Energy (BLE) can use two types of protocol CC25nn or nRF52nn where nn is a specific number. This clock uses nRF52 from the company Nordic.

- Start the app and start a connection with the clock. Some apps automatically start with a connection window but for some a connection symbol must be pressed. You will most probably find one station to select from.

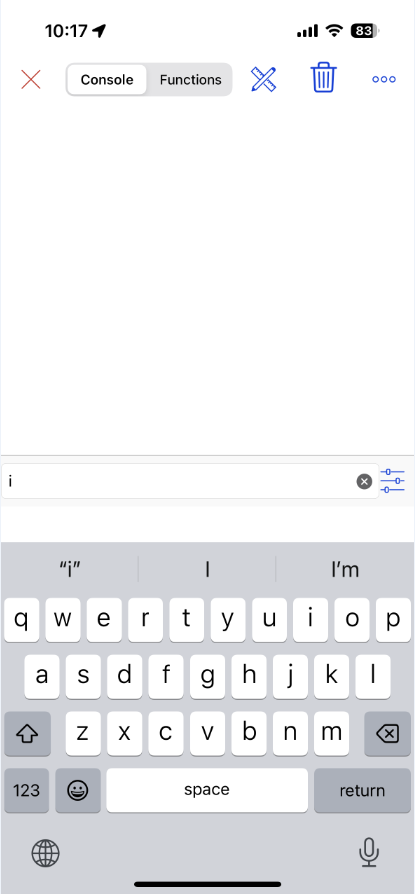
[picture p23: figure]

- Select the clock in the list.
- The app will display a window and a line where commands can be entered and send to the clock.
- Sending the letter I or i for information will display the menu followed with the actual settings of several preferences.

In the clock there is a LED that will have a red dot lighted when the program is running.
A green dot will turn on when there is a WIFI connection. When there is a Bluetooth connection a blue dot in the LED will light.

In both cases send the letter I of Information and the menu shows up.
Enter the first letter of the setting you want to changes followed with a code.
Some entries just toggle On and Off. Like the W to set WIFI Off or On.

To change the SSID and password:
Send the letter A or a followed with the WIFI station name. Amy-ssid and send this command. Eg AFRITZ!Box01 or aFRITZ!Box01. Starting with an upper or lower case character is an identical instruction in the command string Then the letter B followed with the password. Bmypassword and send the password.
Cbroadcastname will change to name displayed in the Bluetooth connection list. Something like: cMyClock

If the length of the SSID and/or password is less then 5 characters the WIFI will be turned off automatically to avoid connection errors.
Use a length of minimal 8 characters for SSID and password. Check in the menu (third row from the bottom) if WIFI and NTP are on.

Enter @ to restart the MCU. It will restart and connections will be made.

Sometimes a second or third reset must be given to get the clock connected to WIFI. If connection still fails check the SSID name and the entered password. (send the letter b, an easter egg))
If WIFI is connected the LED on the MCU will turn on a green dot.

___________________________________
A SSID B Password C BLE beacon name D Date (D15012021) T Time (T132145) E Timezone (E<-02>2 or E<+01>-1) Make own colour of: (Hex RRGGBB) F Font G Dimmed font H Bkgnd
I To print this Info menu
K LDR reads/sec toggle On/Off
L L0 = NL, L1 = UK, L2 = DE
L3 = FR, L4 = Wheel
N Display off between Nhhhh (N2208) O Display toggle On/Off
P Status LED toggle On/Off
Q Display colour choice (Q0-7) Q0 Yellow Q1 hourly
Q2 White Q3 All Own
Q4 Own Q5 Wheel
Q6 Digital Q7 Analog display
R Reset settings @ = Reset MCU --Light intensity settings (1-250)--S=Slope V=Min U=Max (S80 V5 U200) W=WIFI X=NTP& Y=BLE Z=Fast BLE Ed Nieuwenhuys Aug 2023
___________________________________ Display off between: 00h - 00h Display choice: Yellow
Slope: 80 | Min: 5 | Max: 255
SSID: FRITZ!BoxEd
BLE name: PaarseS3N8R2
IP-address: 192.168.178.106 (/update) Timezone:CET-1CEST,M3.5.0,M10.5.0/3 WIFI=On NTP=On BLE=On FastBLE=Off Language choice: Rotate language Software: ESP32C3S3_WordClockV025.ino 02/09/2023 21:06:27
___________________________________
Menu displayed in serial output.

To set a time zone. Send the time zone string between the quotes prefixed with the character E or e.
See the entry strings for the time zones at the bottom of this page.
For example; if you live in Australia/Sydney send the string, eAEST-10AEDT,M10.1.0,M4.1.0/3

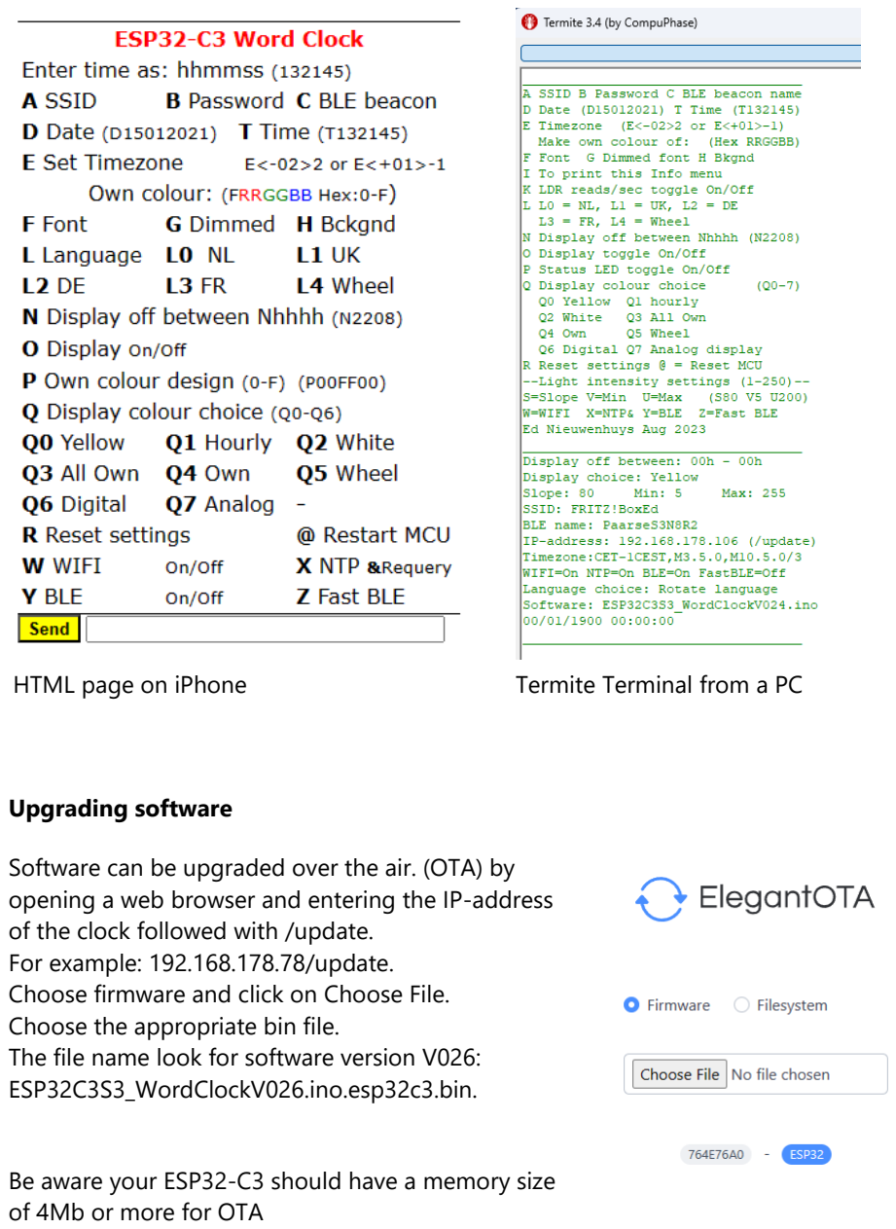
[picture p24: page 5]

HTML page on iPhone | Termite Terminal from a PC

Upgrading software

Software can be upgraded over the air. (OTA) by opening a web browser and entering the IP-address of the clock followed with /update.
For example: 192.168.178.78/update.
Choose firmware and click on Choose File.
Choose the appropriate bin file.
The file name look for software version V026: ESP32C3S3_WordClockV026.ino.esp32c3.bin.

Be aware your ESP32-C3 should have a memory size of 4Mb or more for OTA

Control and settings of the clock

As mentioned before the clock can be controlled with the WIFI webpage or BLE UART terminal app.
When the clock is connected to WIFI the IP-address is displayed when the clock is in Digital display mode. (Q6 in the menu)
The IP-address is also printed in the menu. As a last resort the IP-address can be found in you WIFI router.

To start the menu in a web page the IP-address numbers and dots (for example: 192.168.178.77) must be entered in the web browser of your mobile or PC where you type your internet addresses (URL).

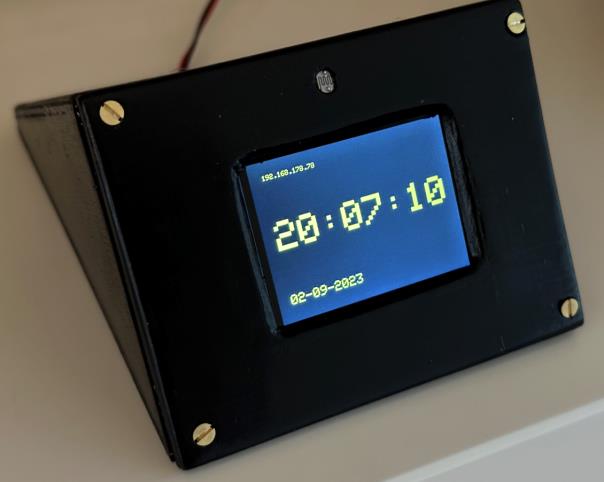
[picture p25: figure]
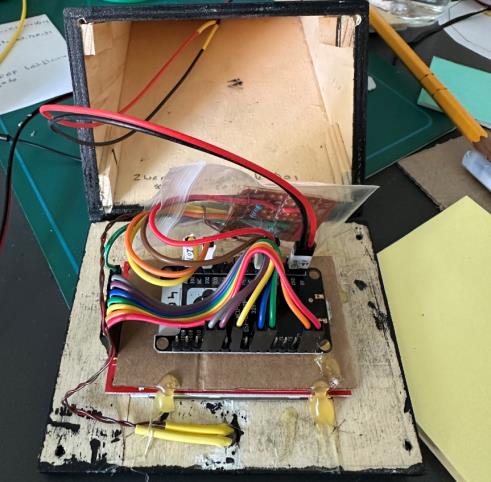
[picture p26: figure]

The triangle clock | Inside of triangle clock

Or with a Bluetooth connection:

Open the BLE terminal app.
Look for the clock to connect to and connect.

Unfortunately some apps can not read strings longer than 20 characters and you will see the strings truncated or garbled.
If you see a garbled menu enter and send the character 'Z' to select the slower transmission mode.
If transmission is too garbled and it is impossible to send the character Z try the web page to send the character Z.
A third method is to use an iPhone, iPad of iMac with the free BLE nRF app.
If all fails you have to connect the MCU inside the clock with a micro USB cable to a PC and use a serial terminal app to send a Z.

Regulating the light intensity of the display

In the menu light intensity of the display can be controlled with three parameters:
--Light intensity settings (1-250)--S=Slope V=Min U=Max (S80 V5 U200) The default values are between the ().

S How fast the brightness reaches maximum brightness. V How bright the display is in complete darkness.
U the maximum brightness of the display.

In the bottom half of the menu the stored values are displayed
Slope: 80 | Min: 5 | Max: 255

The clock reacts on light with its LDR (light dependent
resistor) .
When it gets dark the display does not turn off completely but will stay dimmed at a minimum value.
With the parameter V the lowest brightness can be controlled. With a value between 0 and 255 this brightness can be set.
V5 is the default value.
The maximum brightness of the display is controlled with the parameter
U. Also a value between 0 and 255.
With parameter S the slope can be controlled how fast maximum brightness is achieved.

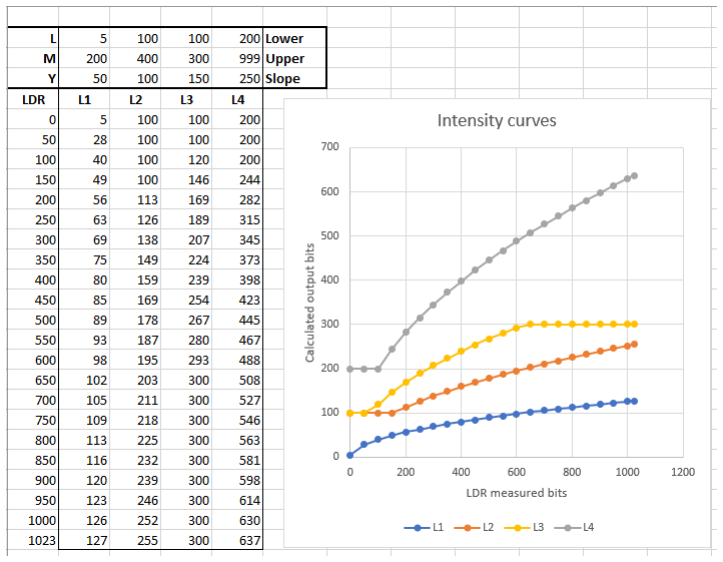
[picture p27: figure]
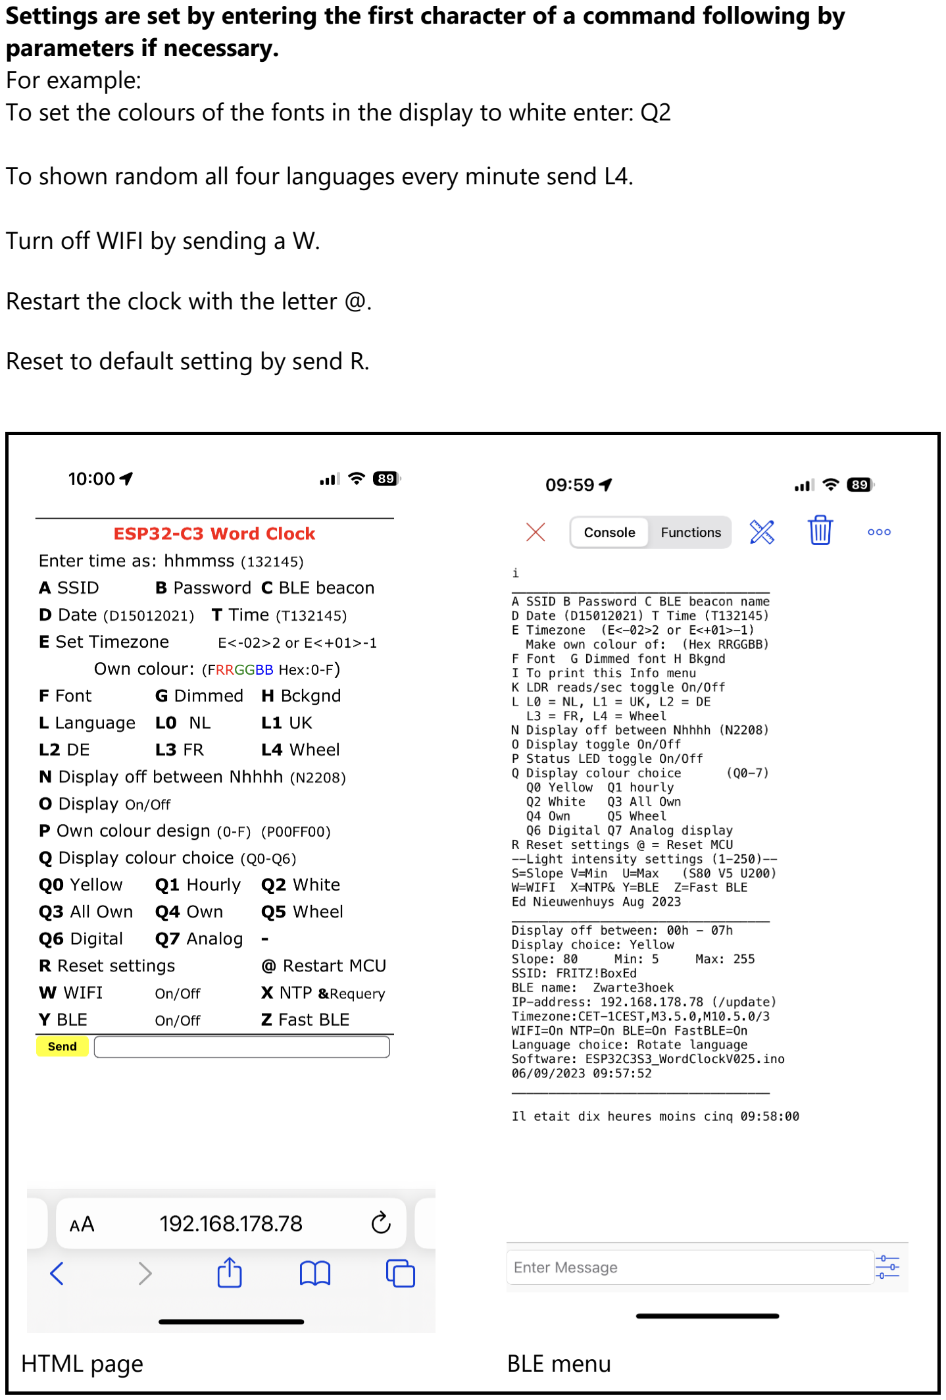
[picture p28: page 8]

Settings are set by entering the first character of a command following by parameters if necessary.
For example:
To set the colours of the fonts in the display to white enter: Q2

To shown random all four languages every minute send L4.

Turn off WIFI by sending a W.

Restart the clock with the letter @.

Reset to default setting by send R.

HTML page | BLE menu

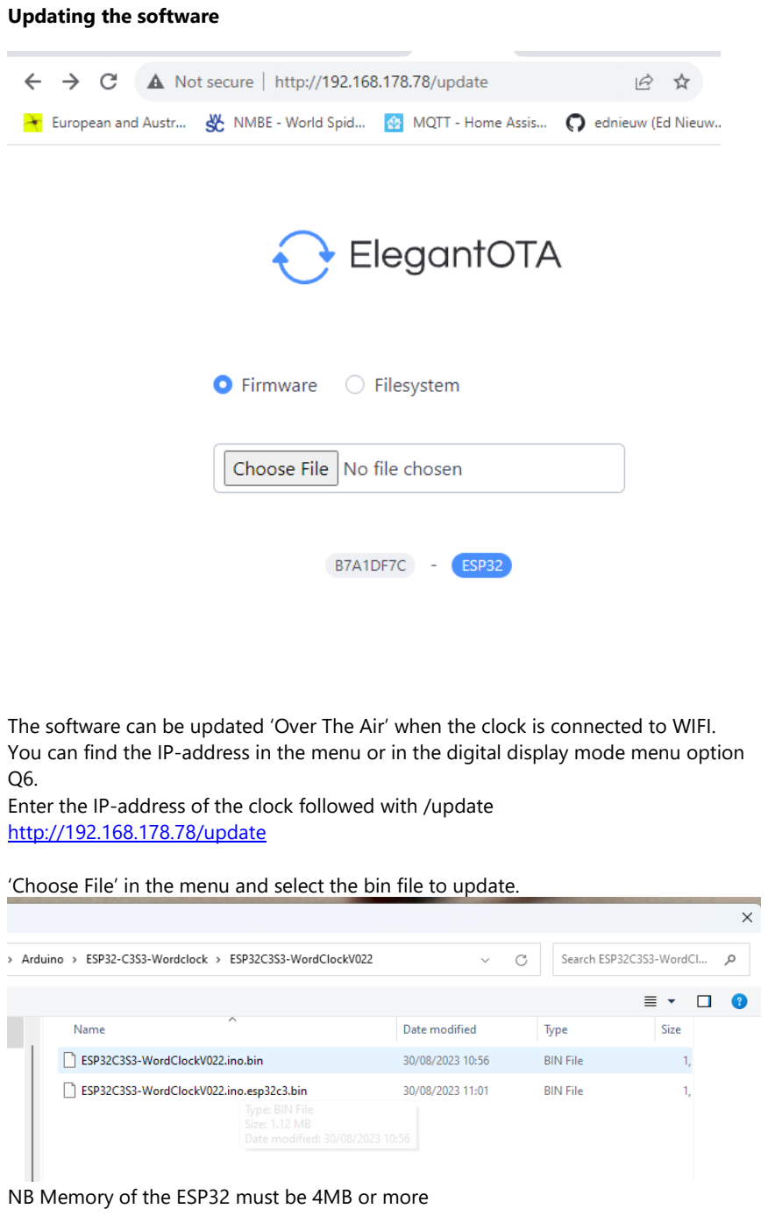
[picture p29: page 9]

Updating the software

The software can be updated ‘Over The Air’ when the clock is connected to WIFI. You can find the IP-address in the menu or in the digital display mode menu option Q6.
Enter the IP-address of the clock followed with /update http://192.168.178.78/update

‘Choose File’ in the menu and select the bin file to update.

NB Memory of the ESP32 must be 4MB or more

Detailed description

With the menu many preferences can be set. These preferences are stored on a SD-card or in the ESP32-C3 storage space.

Enter the first character in the menu of the item to be changed followed with the parameter.
There is no difference between upper or lower case. Both are OK.
Between the ( ).

A SSID B Password C BLE beacon name
Change the name of the SSID of the router to be connected to. For example: aFRITZ!BoxEd or AFRITZ!BoxEd.
Then enter the password. For example: BSecret_password.
Restart the clock by sending @.
Entering a single 'b' will show the used password. This ‘Easter egg’ can be used to check if a valid password was entered.

D Set Date and T Set Time
If you are not connected to WIFI you have to set time and date by hand.
For example enter: D06112022 to set the date to 6 November 2022.

Enter for example T132145 (or 132145 , or t132145) to set the time to 45 seconds and 21 minute past one o'clock.

E Set Timezone E<-02>2 or E<+01>-1
At the bottom of this page you can find the time zones used in 2022.
It is a rather complicated string and it is therefore wise to copy it.
Let's pick one if you happen to live here: Antarctica/Troll,"<+00>0<+02>-2,M3.5.0/1,M10.5.0/3"
Copy the string between the " "'s and send it with starting with an 'E' or 'e' in front. E<+00>0<+02>-2,M3.5.0/1,M10.5.0/3.
Time zones and daylight savings should be ended and replaced by one universal date and time for the while planet cq universe. But that is my opinion.

Make own colour of: (Hex RRGGBB)
F Font G Dimmed font H Bkgnd
You can set the colours of the highlighted and dimmed characters and the background. .
The format to be entered is hexadecimal. 0123456789ABCDEF are the characters that can be used. The command is 2 digits for Red followed with two for Green and ending with two digits for Blue.
To colour the characters intense red enter FF0000 prefixed with the letter F.
To set the background to intense blue enter: H0000FF
To set the dimmed character to dark grey enter for example: G191919. You get grey if red, green and blue has the same intensity.

I To print this Info menu
Print the menu to Bluetooth and the serial monitor connected with an USB-cable.

K Reads/sec toggle On/Off
Entering a K toggles printing of the LDR reading of the measured light intensity. It also shows how many times the processor loops through the program and checks its tasks to run the clock.

L L0 = NL, L1 = UK, L2 = DE, L3 = FR, L4 = Wheel
You can choose between four languages to display or show them randomly every minute.

N Display off between Nhhhh (N2208)
With N2208 the display will be turned off between 22:00 and 8:00.

O Display toggle On/Off
O toggle the display off and on.

P Status LEDs toggle On/Off
P toggle the status LEDs on the MCU off and on.

Q Display colour choice (Q0-6)
Q0 Yellow Q1 hourly Q2 White Q3 All Own Q4 Own Q5 Wheel Q6 Digital display

Q0 will show the time with yellow words.
Q1 will show every hour another colour.
Q2 shows all the texts white.
Q3 and Q4 uses you own defined colours.
Q5 will follow rainbow colours every minute.
Q6 is the digital display with the IP-address and date until seconds are 00. Q7 is the analogue clock

R Reset settings
R will set all preferences to default settings, it also clears the SSID and password.

--Light intensity settings (1-250)--
S=Slope V=Min U=Max (S80 V5 U200)
The

@ = Reset MCU
@ will restart the MCU. This is handy when the SSID, et cetera are changed and the program must be restarted. Settings will not be deleted.

W=WIFI, X=NTP&, Y=BLE, Z=Use SD Toggle WIFI, NTP on and off.
Enter the character will toggle it on or off.

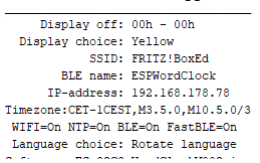
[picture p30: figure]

At the bottom of the menu the stated is printed.

Sending a & will start a query from the time server.

Z Fast BLE
The BLE UART protocol sends default packets of 20 bytes. Between every packet there is a delay of 50 msec.
The IOS BLEserial app, and maybe others too, is able to receive packets of 80 bytes or more before characters are missed.
Option Z toggles between the long and short packages.

Known issues

Sometimes the clock looses the WIFI connection. You will not notice it directly because the internal clock will keep the clock on time for a few days.
When connection is lost the clock will try to reconnect every hour.
If you still see 0.0.0.0 in the digital display mode restart the clock or turn it off and on.
When restarting the clock the clock will not always make a WIFI connection and gets an IP-address.
Just Reset with @ in the menu until an IP-address other than 0.0.0.0 is displayed when starting or in the digital display.

How to build the clock can be found here: https://ednieuw.home.xs4all.nl/Woordklok/ESP32C3AndMore/ESP32C3ClockAndMoreV.htmlhttps://github.com/ednieuw/ESP32-C3-Clock-and-more

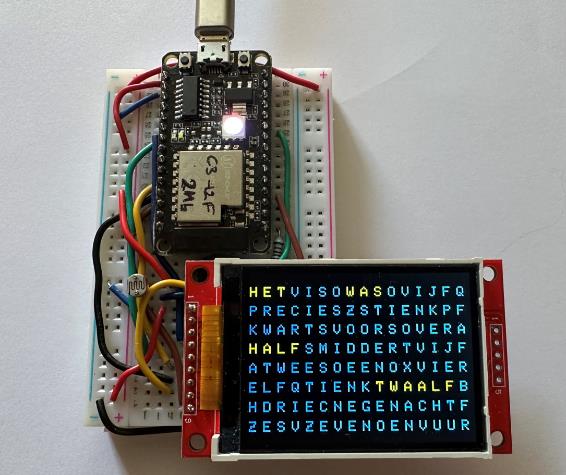
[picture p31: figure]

Prototype of the clock.

@Ed Nieuwenhuys, September 2023

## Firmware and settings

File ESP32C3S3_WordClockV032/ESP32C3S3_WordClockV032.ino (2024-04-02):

/* 

--------------------------------------  
 Author .    : Ed Nieuwenhuys
 Changes V001: Derived from PocuterWordClockV052
 Changes V002: Stable version without ILI 9341 display / SD card
 Changes V003: Added ILI9341
 Changes V004: Screen layout. Displayprintln()
 Changes V005: BT connection on led blue, repait digitalprint. Turn off LEDs after 1 minute 
 Changes V006: LDR and Backlight regulation
 Changes V007: Debugging
 Changes V008: Added Light intensity S Slope T Min U Max
 Changes V009: Clean up code. Can be used with the ILI9341 Display. 
 Changes V010: Added a SK6812 LED-strip for a 4-language word clock 
 Changes V011: Compiles also for ESP32-S3. Added menu option & for requery NTP 
 Changes V012: Using ledcSetup(ledChannel, freq, resolution); to remove display flickering
               timeinfo.tm_mon starts at januari = 0 
               Menu entry & forces NTP update
               Digital display on screen updated
 Changes V013: Analog clock added as option
 Changes V014: Redecorated the analog clock
 Changes V015: Built analogue clock
 Changes V016: Built analogue clock. Corrected month in NTP. month 0 is janyary
 Changes V017: Stable
 Changes V018: SetStatusLED ESP32-s3
 Changes V019: Added WiFi.onEvents for connection and error coes and proper connection handling.
               WIFI.Events worked fine but ....
               Discontinued with ILI9341. Using WiFi.onEvent interrupts and crashes screen display while writing the screen
 Changes V020: Added OTA. This version compiles and runs on ESP32-C3. 
 Changes V021: Develop/Testing. Mem menory expanded. restart ESP32 once after first boot when no IP-addreess cq connection. 
 Changes V022: Works with SP32-C3. OTA fails with 2MB esp32-C3. Too less memory
 Changes V023: Works with SP32-C3.
 Changes V024: Corrected some compiler warnings 
 Changes V025: Isolate display functions to make it easy to add another display. Optimized lockup during printing to ILI9341 display
 Changes V026: If WIFI connection is lost reconnect every hour. Turn off Red LED after startup if Display LEDs is off
 Changes V027: Solved analog clock outer ring not shown after display off -> Added void RestartDisplay(void)
 Changes V028: Hour hand nicer. 
 Changes V029: Stable version. 
 Changes V030: Added ESP32-C3-supermini
               For ESP32 with RGBW SK6812 Led strip see ESP32Arduino_WordClockV0nn
 Changes V031: ESP32-V3.0.0 
 Changes V032: Corrected SetRTCtime() struct timeval now = { .tv_sec = t , .tv_usec = t}; --> struct timeval now = { .tv_sec = t};

 
 Changed in Setup()
            ledcSetup(0, 5000, 8);        //ledChannel, freq, resolution);                               // configure LED PWM functionalitites 5000 Hz, 8 bits
            ledcAttachPin(TFT_LED, 0);  //ledPin, ledChannel);                                           // ILI9341 backlight on ledchannel 0 and GPIO pin TFT_LED
            --->
          ledcAttach(TFT_LED, 5000, 8);  //ledPin, freq, resolution, ledChannel);                     // ILI9341 backlight on ledchannel 0 and GPIO pin TFT_LED


 ToDo:
 Use WIFI events with faster displays
 Help scherm uitprinten
 Store serial-print per dag op SD per maand for debugging purposes

How to compile: Install ESP32 boards
Set to:
Board: ESP32-C3 DEV module or ESP32-S3 DEV module
Flash size 4MB ot 2MB if you have a cheaper 2MB board.
OTA will not wotk on 2MB boards
Patition Scheme: Default or change to Minimal SPIFFS (1.9Mb with OTA, 190kB SPIFFS) if there is a memoty shortage


// ESP32-C3-12F layout seen from top
// ADC   ----- I0 19
// IO 01 ----- I0 18
// NC    ----- I0 10
// IO 02 ----- I0 09
// IO 03 ----- I0 08
// IO 04 ----- 3V3  
// IO 05 ----- GND  
// NC    ----- NC   
// NC    ----- I0 06
// GND   ----- I0 07
// 3V3   ----- NC   
// EN    ----- RX   
// IO 00 ----- TX   
// GND   ----- GND  
// 5V    ----- 3V3  

ILI9341 connections
MISO  to GPIO 10
LED   to 3V3
SCK   to GPIO 09
MOSI  to GPIO 08  
DC/RS to GPIO 06
RESET to GPIO 07
CS    to GND
GND   to GND
3V3   to 3V3
 
Usage of:
1 Screen, colours and fonts
2 BLE nRF UART connection with phone
3 Buttons
4 RGB LED
5 RTC module for time
6 ??SD-card or SPIFFS storage of a struct with settings
7 Get timezone corrected time with daylight savings from a NTP server via WIFI
8 Menu driven with serial monitor, BLE and WIFI
9 Change connection settings of WIFI via BLE
10 Get time with NTP server via WIFI
11 OTA updates of the software by WIFI

Starting the monitor will result in the board to be unresponsive. This is due to the CTS and RTS levels of the serial interface. Disabling the control lines prevents the board to become unresponsive. Edit the file “boards.txt” from the definition of the board. The file is located in the following directory, where xxxxx is the user name: “C:\Users\xxxxx\AppData\Local\Arduino15\packages\esp32\hardware\esp32\2.0.2”
To get to this location, find c:\Users\ednie\AppData\Local\Arduino15\packages\esp32\hardware\esp32\(2.0.9 or higher version )\boards.txt

esp32c3.serial.disableDTR=false
esp32c3.serial.disableRTS=false
to
esp32c3.serial.disableDTR=true
esp32c3.serial.disableRTS=true    

or of you have an s3 board esp32s3.serial....
               
*/
// =============================================================================================================================
#define ESP32C3_SUPERMINI
//#define ESP32C3_DEV
//#define ESP32S3_DEV
//#define ILI9341
//--------------------------------------------
// ESP32-C3 Includes defines and initialisations
//--------------------------------------------

#include <NimBLEDevice.h>      // For BLE communication  https://github.com/h2zero/NimBLE-Arduino
#include <ESPNtpClient.h>      // https://github.com/gmag11/ESPNtpClient
#include <WiFi.h>              // Used for web page 
#include <AsyncTCP.h>          // Used for webpage   https://github.com/me-no-dev/ESPAsyncWebServer
#include <ESPAsyncWebServer.h> // Used for webpage   https://github.com/me-no-dev/ESPAsyncWebServer
#include <AsyncElegantOTA.h>   // Used for OTA
#include <Preferences.h>
#include "Colors.h"
                        #ifdef ILI9341
#include <Adafruit_ILI9341.h>  // https://github.com/adafruit/Adafruit_ILI9341
//#include <Adafruit_GFX.h>      // Core graphics library, with extra fonts.
                        #endif // ILI9341
#define HET     ColorLeds("Het",     0,   2, MINColor);   
#define IS      ColorLeds("is",      4,   5, SECColor);    Is = true; 
#define WAS     ColorLeds("was",     7,   9, SECColor);    Is = false;
#define MVIJF   ColorLeds("vijf",    11, 14, LetterColor); 
#define PRECIES ColorLeds("precies", 16, 22, LetterColor);
#define MTIEN   ColorLeds("tien",    25, 28, LetterColor); 
#define KWART   ColorLeds("kwart",   32, 36, LetterColor);
#define VOOR    ColorLeds("voor",    38, 41, LetterColor);
#define OVER    ColorLeds("over",    43, 46, LetterColor);
#define HALF    ColorLeds("half",    48, 51, LetterColor);
#define MIDDER  ColorLeds("midder",  53, 58, LetterColor);
#define VIJF    ColorLeds("vijf",    60, 63, LetterColor);
#define TWEE    ColorLeds("twee",    65, 68, LetterColor);
#define EEN     ColorLeds("een",     71, 73, LetterColor);
#define VIER    ColorLeds("vier",    76, 79, LetterColor);
#define ELF     ColorLeds("elf",     80, 82, LetterColor);
#define TIEN    ColorLeds("tien",    84, 87, LetterColor);
#define TWAALF  ColorLeds("twaalf",  89, 94, LetterColor);
#define DRIE    ColorLeds("drie",    97,100, LetterColor);
#define NEGEN   ColorLeds("negen",  102,106, LetterColor);
#define ACHT    ColorLeds("acht",   107,110, LetterColor);
#define NACHT   ColorLeds("nacht",  114,118, LetterColor);
#define ZES     ColorLeds("zes",    112,114, LetterColor);
#define ZEVEN   ColorLeds("zeven",  116,120, LetterColor);
#define NOEN    ColorLeds("noen",   120,123, LetterColor);
#define UUR     ColorLeds("uur",    125,127, LetterColor);
//#define EDSOFT  ColorLeds("EdSoft", 132,132, LetterColor);
#define X_OFF   ColorLeds("",         0,  2, 0);
#define X_ON    ColorLeds("",         0,  2, LetterColor);

#define IT      ColorLeds("It",     1,   2, MINColor);   
#define ISUK    ColorLeds("is",       4,   5, SECColor);    Is = true;
#define WASUK   ColorLeds("was",      7,   9, SECColor);    Is = false;
#define EXACTUK ColorLeds("exact",   11,  15, LetterColor);
#define HALFUK  ColorLeds("half",    16,  19, LetterColor); 
#define TWENTY  ColorLeds("twenty",  21,  26, LetterColor); 
#define MFIVE   ColorLeds("five",    28,  31, LetterColor);
#define QUARTER ColorLeds("quarter", 32,  38, LetterColor);
#define MTEN    ColorLeds("ten",     39,  41, LetterColor);
#define PAST    ColorLeds("past",    43,  46, LetterColor);
#define TO      ColorLeds("to",      48,  49, LetterColor);
#define MID     ColorLeds("mid",     53,  55, LetterColor);
#define SIXUK   ColorLeds("six",     57,  59, LetterColor);
#define TWO     ColorLeds("two",     61,  63, LetterColor);
#define FIVE    ColorLeds("five",    64,  67, LetterColor);
#define TWELVE  ColorLeds("twelve",  69,  74, LetterColor);
#define TEN     ColorLeds("ten",     76,  78, LetterColor);
#define ELEVEN  ColorLeds("eleven",  80,  85, LetterColor);
#define FOUR    ColorLeds("four",    88,  91, LetterColor);
#define ONE     ColorLeds("one",     93,  95, LetterColor);
#define EIGHT   ColorLeds("eight",   97, 101, LetterColor);
#define THREE   ColorLeds("three",  101, 105, LetterColor);
#define NIGHT   ColorLeds("night",  106, 110, LetterColor);
#define NINE    ColorLeds("nine",   112, 115, LetterColor);
#define SEVEN   ColorLeds("seven",  116, 120, LetterColor);
#define OCLOCK  ColorLeds("O'clock", 122, 127, LetterColor);

#define ES      ColorLeds("Es",       0,   1, MINColor);   
#define IST     ColorLeds("ist",      3,   5, SECColor);    Is = true;
#define WAR     ColorLeds("war",      6,   8, SECColor);    Is = false;
#define GENAU   ColorLeds("genau",   10,  14, LetterColor);
#define MZEHN   ColorLeds("zehn",    16,  19, LetterColor);
#define MFUNF   ColorLeds("funf",    20,  23, LetterColor);
#define VIERTEL ColorLeds("viertel", 24,  30, LetterColor);
#define ZWANZIG ColorLeds("zwanzig", 32,  38, LetterColor);
#define KURZ    ColorLeds("kurz",    40,  43, LetterColor);
#define VOR     ColorLeds("vor",     45,  47, LetterColor);
#define NACH    ColorLeds("nach",    48,  51, LetterColor);
#define HALB    ColorLeds("halb",    53,  56, LetterColor);
#define FUNF    ColorLeds("funf",    58,  61, LetterColor);
#define EINS    ColorLeds("eins",    64,  67, LetterColor);
#define VIERDE  ColorLeds("vier",    69,  72, LetterColor);
#define ZWOLF   ColorLeds("zwolf",   73,  77, LetterColor);
#define MITTER  ColorLeds("mitter",  80,  85, LetterColor);
#define ACHTDE  ColorLeds("acht",    87,  90, LetterColor);
#define NACHTDE ColorLeds("nacht",   86,  90, LetterColor);
#define DREI    ColorLeds("drei",    92,  95, LetterColor);
#define SECHS   ColorLeds("sechs",   96, 100, LetterColor);
#define SIEBEN  ColorLeds("sieben", 102, 107, LetterColor);
#define NEUN    ColorLeds("neun",    107, 110, LetterColor);
#define ZWEI    ColorLeds("zwei",   112, 115, LetterColor);
#define ZEHN    ColorLeds("zehn",   116, 119, LetterColor);
#define ELFDE   ColorLeds("elf",    120, 122, LetterColor);
#define UHR     ColorLeds("uhr",    125, 127, LetterColor);

#define IL      ColorLeds("Il",       0,   1, MINColor);   
#define EST     ColorLeds("est",      3,   5, SECColor);    Is = true;
#define ETAIT   ColorLeds("etait",    6,  10, SECColor);    Is = false;
#define EXACT   ColorLeds("exact",   11,  15, LetterColor);
#define SIX     ColorLeds("six",     16,  18, LetterColor); 
#define DEUX    ColorLeds("deux",    19,  22, LetterColor); 
#define TROIS   ColorLeds("trois",   23,  27, LetterColor);
#define ONZE    ColorLeds("onze",    28,  31, LetterColor);
#define QUATRE  ColorLeds("quatre",  32,  37, LetterColor);
#define MINUIT  ColorLeds("minuit",  39,  44, LetterColor);
#define DIX     ColorLeds("dix",     45,  47, LetterColor);
#define CINQ    ColorLeds("cinq",    48,  51, LetterColor);
#define NEUF    ColorLeds("neuf",    52,  55, LetterColor);
#define MIDI    ColorLeds("midi",    57,  60, LetterColor);
#define HUIT    ColorLeds("huit",    64,  67, LetterColor);
#define SEPT    ColorLeds("sept",    69,  72, LetterColor);
#define UNE     ColorLeds("une",     73,  75, LetterColor);
#define HEURE   ColorLeds("heure",   80,  84, LetterColor);
#define HEURES  ColorLeds("heures",  80,  85, LetterColor);
#define ET      ColorLeds("et",      87,  88, LetterColor);
#define MOINS   ColorLeds("moins",   90,  94, LetterColor);
#define LE      ColorLeds("le",      96,  97, LetterColor);
#define DEMI    ColorLeds("demie",   99, 103, LetterColor);
#define QUART   ColorLeds("quart",  106, 110, LetterColor);
#define MDIX    ColorLeds("dix",    112, 114, LetterColor);
#define VINGT   ColorLeds("vingt",  116, 120, LetterColor);
#define MCINQ   ColorLeds("cinq",   122, 125, LetterColor);
#define DITLEHEURE DitLeHeure();

//--------------------------------------------
// SPIFFS storage
//--------------------------------------------
Preferences FLASHSTOR;

 //--------------------------------------------
// COLOURS stored in Mem.DisplayChoice
//--------------------------------------------   

const byte DEFAULTCOLOUR = 0;
const byte HOURLYCOLOUR  = 1;          
const byte WHITECOLOR    = 2;
const byte OWNCOLOUR     = 3;
const byte OWNHETISCLR   = 4;
const byte WHEELCOLOR    = 5;
const byte DIGITAL       = 6;
const byte ANALOOG       = 7;

// Pin Assignments
#define  PhotoCellPin 2
#define  EMPTY01      1
#define  EMPTY00      0
#define  RGB_LED     38

                        #ifdef ESP32C3_DEV

#define  REDPIN       3
#define  GREENPIN     4
#define  BLUEPIN      5
#define  COLD_WHITE  18
#define  WARM_WHITE  19
                        #endif

                        
//--------------------------------------------                                                //
// ESP32-C3 initialysations
//--------------------------------------------
bool     PrintDigital = false;                                                                // Show digital display 
bool     IP_Printed   = false;                                                                // The IP address will be printed on the display
bool     Date_Printed = false;                                                                // The date will be printed on the display  
char     Template[140];                                                                       // Contains the string with characters to be printed in the display
uint32_t LastButtonTime = 0;                                                                  // Used to avoid debouncing the button

//------------------------------------------------------------------------------
// LDR PHOTOCELL
//------------------------------------------------------------------------------
//                                                                                            //
const byte SLOPEBRIGHTNESS  = 80;                                                             // Steepness of with luminosity of the LED increases
const int  MAXBRIGHTNESS    = 255;                                                            // Maximun value in bits  for luminosity of the LEDs (1 - 255)
const byte LOWBRIGHTNESS    = 5;                                                              // Lower limit in bits of Brightness ( 0 - 255)   
byte     TestLDR            = 0;                                                              // If true LDR inf0 is printed every second in serial monitor
int      OutPhotocell;                                                                        // stores reading of photocell;
int      MinPhotocell       = 999;                                                            // stores minimum reading of photocell;
int      MaxPhotocell       = 1;                                                              // stores maximum reading of photocell;
uint32_t SumLDRreadshour    = 0;
uint32_t NoofLDRreadshour   = 0;

//--------------------------------------------
// CLOCK initialysations
//--------------------------------------------
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
void loop() 
{
 Loopcounter++;
 EverySecondCheck();  
 CheckDevices();
}
//--------------------------------------------
// Common Check connected input devices
//--------------------------------------------
void CheckDevices(void)
{
 CheckBLE();                                                                                  // Something with BLE to do?
 SerialCheck();                                                                               // Check serial port every second 
// ButtonsCheck();                                                                            // Check if buttons pressed
}
//--------------------------------------------                                                //
// CLOCK Update routine done every second
//--------------------------------------------
void EverySecondCheck(void)
{
 //static int lumi=0;
 uint32_t msLeap;
 
 msLeap = millis() - msTick;                                                                  // uint32_t msLeapButton = millis()- LastButtonTime;
 if (msLeap >999)                                                                             // Every second enter the loop
  { 
   msTick = millis();
   if (msLeap%500==0  && Mem.StatusLEDOnOff)                                                  // Do not update the LED unnecesary often.It takes a lot of msecs per update
       SetStatusLED(0,0,6,6*WIFIConnected,6*deviceConnected);  
   GetTijd(0);                                                                                // Update timeinfo.tm_sec, timeinfo.tm_min, timeinfo.tm_hour, timeinfo.tm_mday, timeinfo.tm_mon, timeinfo.tm_year
   if(!LEDsAreOff) ScreenSecondProcess();                                                                     // Draw seconds in digital and analogue display mode
   DimLeds(TestLDR);                                                                          // Every second an intensitiy check and update from LDR reading 
   if (timeinfo.tm_min != lastminute) EveryMinuteUpdate();                                    // Enter the every minute routine after one minute; 
//   if (Loopcounter < 10) ESP.restart();
   Loopcounter=0;
  }  
 }
//--------------------------------------------
// CLOCK Update routine done every minute
//-------------------------------------------- 
void EveryMinuteUpdate(void)
{   
 lastminute = timeinfo.tm_min;  
 if(!LEDsAreOff)  Displaytime();                                                              // Turn the display on                 
// Print_tijd();                                                                              // sprintf(sptext,"NTP:%s", NTP.getTimeDateString());   Tekstprintln(sptext);  
 //  if(WiFi.localIP()[0]>0) WIFIConnected = true; else WIFIConnected = false;                  // To be sure connection is still there
 if(timeinfo.tm_hour != lasthour) EveryHourUpdate();
}
//--------------------------------------------
// CLOCK Update routine done every hour
//--------------------------------------------
void EveryHourUpdate(void)
{
 if(WiFi.localIP()[0]==0)
   {
     sprintf(sptext, "Disconnected from station, attempting reconnection");
     Tekstprintln(sptext);
     WiFi.reconnect();
   }
 lasthour = timeinfo.tm_hour;
 if (!Mem.StatusLEDOnOff) SetStatusLED(0,0,0,0,0);                                            // If for some reason the LEDs are ON and after a MCU restart turn them off.  
 if(timeinfo.tm_hour == Mem.TurnOffLEDsAtHH){ LEDsAreOff = true;  ClearScreen();    }         // Is it time to turn off the LEDs?
 if(timeinfo.tm_hour == Mem.TurnOnLEDsAtHH) { LEDsAreOff = false; RestartDisplay(); }         // Redraw the outer rings of the analog clock if necessary 
 Mem.NVRAMmem[lasthour] =(byte)((SumLDRreadshour / NoofLDRreadshour?NoofLDRreadshour:1));     // Update the average LDR readings per hour
 SumLDRreadshour  = 0;
 NoofLDRreadshour = 0;
 if (timeinfo.tm_mday != lastday) EveryDayUpdate();  
}
//--------------------------------------------                                                //
// CLOCK Update routine done every day
//------------------------------------------------------------------------------
void EveryDayUpdate(void)
{
 if(timeinfo.tm_mday != lastday) 
   {
    lastday = timeinfo.tm_mday; 
    Previous_LDR_read = ReadLDR();                                                            // to have a start value
    MinPhotocell      = Previous_LDR_read;                                                    // Stores minimum reading of photocell;
    MaxPhotocell      = Previous_LDR_read;                                                    // Stores maximum reading of photocell;
//    StoreStructInFlashMemory();                                                             // 
    }
}
//--------------------------------------------
// Common check for serial input
//--------------------------------------------
void SerialCheck(void)
{
 String SerialString; 
 while (Serial.available())
    { 
     char c = Serial.read();                                                                  // Serial.write(c);
     if (c>31 && c<128) SerialString += c;                                                    // Allow input from Space - Del
     else c = 0;                                                                              // Delete a CR
    }
 if (SerialString.length()>0) 
    {
     ReworkInputString(SerialString+"\n");                                                    // Rework ReworkInputString();
     SerialString = "";
    }
}
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

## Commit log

2022-11-29 Delete ESp32C3-WordClockV002 directory
    Outdated
2022-11-29 Delete ESp32C3-WordClockV003 directory
    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
2022-11-29 Delete ESp32C3-WordClockV008 directory
    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
2022-12-03 Url’s
2023-05-10 V011 For ESP32C3 and ESP32-S3
2023-09-21 V026
    Changes V024: Corrected some compiler warnings
    Changes V025: Isolate display functions to make it easy to add another display. Optimized lockup during printing to ILI9341 display
    Changes V026: If WIFI connection is lost reconnect every hour
2023-09-21 Delete ESP32C3S3_WordClockV025 directory
    replaced with V026
2023-11-03 V027
    Changes V021: Develop/Testing. Mem menory expanded. restart ESP32 once after first boot when no IP-addreess cq connection.
    Changes V022: Works with SP32-C3. OTA fails with 2MB esp32-C3. Too less memory
    Changes V023: Works with SP32-C3.
    Changes V026: If WIFI connection is lost reconnect every hour. Turn off Red LED after startup if Display LEDs is off
    Changes V027: Solved analog clock outer ring not shown after display off -> Added void RestartDisplay(void)
    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
    [ESP32C3S3_WordClockV027.ino]
2023-11-05 Add files via upload
    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
    [ESP32C3S3_WordClockV027.ino]
2023-11-05 V027
    Changes V001: Derived from PocuterWordClockV052
    Changes V002: Stable version without ILI 9341 display / SD card
    Changes V003: Added ILI9341
    Changes V004: Screen layout. Displayprintln()
    Changes V005: BT connection on led blue, repait digitalprint. Turn off LEDs after 1 minute
    Changes V006: LDR and Backlight regulation
    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
2024-04-02 V032
    Changes V020: Added OTA. This version compiles and runs on ESP32-C3.
    Changes V027: Solved analog clock outer ring not shown after display off ->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
    [ESP32C3S3_WordClockV032.ino]
